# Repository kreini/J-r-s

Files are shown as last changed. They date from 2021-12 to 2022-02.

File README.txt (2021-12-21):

Járásvizsgáló eszköz

Ez az eszköz eredetileg a 29. Tudományos és Innovációs Tehetségkutató versenyre készült, melyet azóta számos alkalommal továbbfejlesztettünk, illetve számos másik versenyen is indultunk vele, mint különböző intézmények TDK-ján, illetve a 35. OTDK-n.

Ezen az adattárban az ennek a fejlesztése során létrejött programok és dokumentációk találhatók meg. A fő könyvtárak, melyek itt találhatók:

- OTDK 2021: A 35. OTDK-ra készült dokumentumok találhatók meg itt
- PosTracker: Az első 3 verzió, és a hozzá tartozó fájlokat tartalmazza
- TDK 2020 SOTE: A Semmelweis Egyetem TDK-jára készült dokumentumok
- TDK 2020: A BME-s TDK-ra készült dokumentumok helye
- TDK 2021: A BME-s TDK-ra készült dokumentumok, illetve kódok, modellek és mérések itt találhatók meg
- pályázatok: A különböző pályázatokhoz szükséges dokumentumok ebben a mappában vannak

Ez a projekt jelenleg az 5. verziónál tart, mely a TDK 2021 mappában található. Jelenleg saját NYÁK fejlesztésénél tartunk, azzal kapcsolatban lesznek további fejlesztések

Kreinicker Gábor, 2021

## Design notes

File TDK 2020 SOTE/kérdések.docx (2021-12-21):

A mi adataink milyen viszonyban vannak a már orvosilag alkalmazott eszközök adataival?

Mit jelent az, hogy „nehezen vizsgálható összefüggések”?

Mi alapján döntöttük el, hova kerüljenek a szenzorok?

Honnan jött az ötlet?

Miért van szükség két Arduinora?

Miért nem elég a Raspberry?

Mennyire megbízható egy kínai eszköz orvosi alkalmazása?

Mennyi ideig bírja akkumulátoridővel, milyen hosszú mérést lehet vele csinálni?

Miért van két érték a mintavételezésnél a táblázatnál?

Mit jelent az, hogy „elegendően pontos” a táblázatnál?

Mérünk mind a 9 DoF-ban? Miért / miért nem?

Miért van szükség az adatok utólagos ilyen szintű feldolgozására?

Hasonlítottuk-e már össze élőben a mi eszközünket más hasonló eszközökkel?

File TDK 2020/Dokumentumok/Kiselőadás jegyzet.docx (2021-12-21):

KSH:

- minden 5. felnőttnek nehézséget okoz a járás
- gyerekkorban fejlődik ki, ezért lenne jelentős a szűrése

Hasonló rendszerek

- Az orvostudomány több területein már használnak megfelelő szűrő eszközöket

Ezek jól beváltak: EKG okosóra, 24 órás vérnyomásmérők

- Probléma: A járás is nagyon fontos, mégsem szűrik megfelelően

Jelenleg használt technológiák járásszervi rendellenesség szűrésére:

- MoCap:

szobában levő kamerák veszik a páciensen elhelyezett elkülönülő pontokat, melyek pozícióját szoftveresen tudják számolni

Probléma: Sok idő, kis hely, fehérköpeny effektus

- Mienkéhez hasonló eszközök

Nagyon drágák és kis testreszabhatóság

Járáshibák:

Öt jelentős járáshiba megemlítése → ezek teljes kialakulásának megelőzése lenne a cél

- görcsös járás: feszült testtartás
- ollózva járás: a térdek befordulnak
- előre dőlt járás: ami a neve, deréktól fölfelé előre van dőlve a bácsi
- lábejtő járás: egyik lábára ráhuppan, a másikat pedig vonszolja
- vándorgó járás: felső testből oldalirányba nagy kitérések (+ gyerekeknél: lábujjhegyen járás)

A szenzorok

- MPU-9250 típusú szenzor, giroszkóp, gyorsulásmérő és magnetométer
- 7db van: 2db lábfej, 2db vádli, 2db comb és 1db derék
- Saját tervezésű és 3d nyomtatott tokozás: 3.) első verzió, 1.) harmadik verzió (most készül)

Amivel mértünk, az a második verzió (lapozás)

Az egész működése

- Az MPU szenzorok I2C buszon keresztül kommunikálnak 1-1 Ardunio Nano uvezérlővel

1 nano – 3 MPU, 1 nano – 4 MPU

- Egy szenzort akár 1000Hz-en is tudtuk olvasni, azonban több olvasásával ez lecsökkent 120-140Hz-re szenzoronként (több szenzort olvasunk + átkapcsolás)
- alvó mód → ébresztés → mintavételezés → altatás
- Az arduinok soros porton keresztül kommunikálnak a Raspberry pi 4 model B-vel, ami a beérkező adatokat a 4gb-nyi ramban tárolja, majd kimenti egy fájlba és továbbküldi vezeték nélkül (wifi) egy vele összekötött számítógépnek.

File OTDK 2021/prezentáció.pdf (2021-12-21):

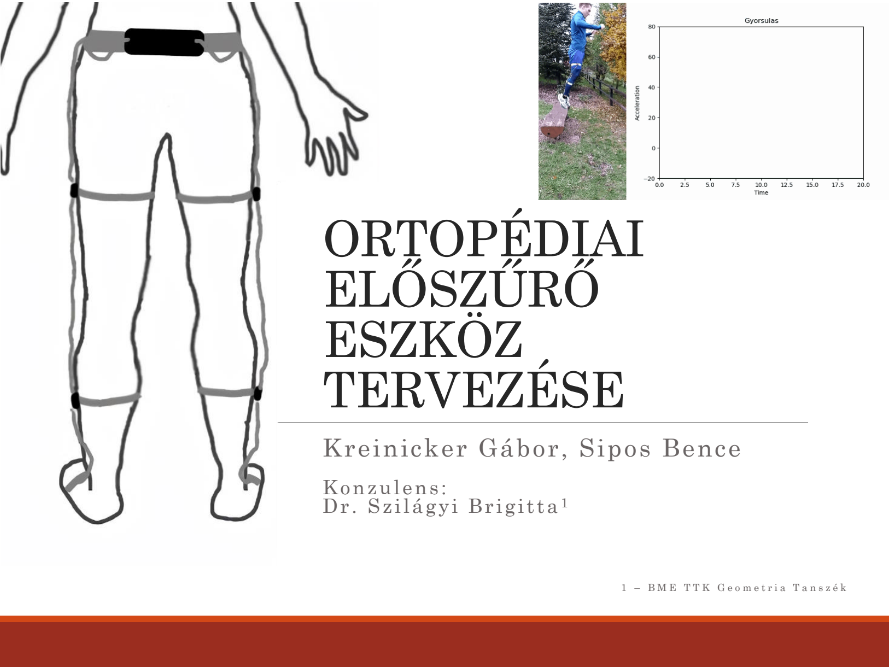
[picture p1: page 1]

# ORTOPÉDIAI ELŐSZŰRŐ ESZKÖZ TERVEZÉSE

# Kreinicker Gábor, Sipos Bence

## Konzulens: Dr. Szilágyi Brigitta ¹

1 – B M E T T K G e o m e t r i a T a n s z é k

# Járásproblémák

ORTOPÉDIAI ELŐSZŰRŐ ESZKÖZ TERVEZÉSE | 2

Képek forrása:
https://www.ksh.hu/apps/shop.kiadvany?p_kiadvany_id=1057181&p_temakor_kod=KSH&p_lang=HU

# Jelenlegi vizsgálatok

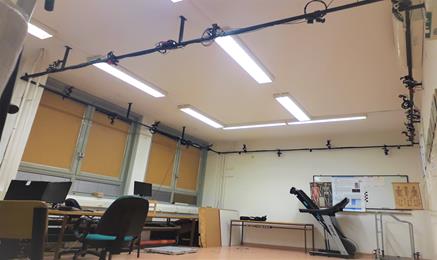
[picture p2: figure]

Képek forrása:

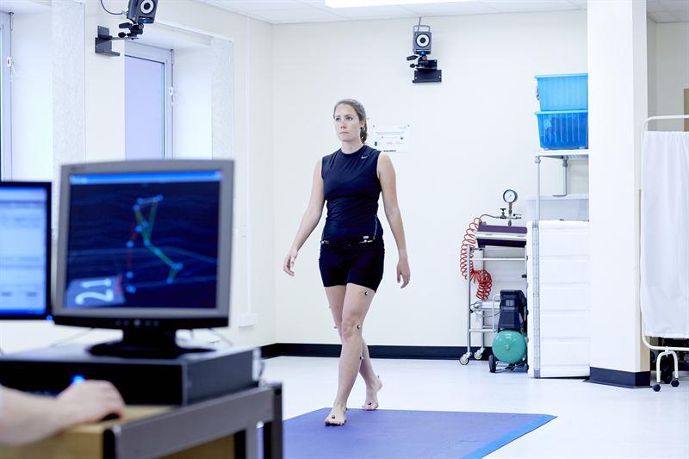
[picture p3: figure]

https://news.cision.com/vicon/r/motion-capture-set-to-become-more-mainstream-in-medical-science-predicts-vicon,c9722569 Molnár Cecília képe

# Járásvizsgálatok fontossága

# - Megfelelő időben való észlelése fontos (idősek esései) (Begg et al., 2000) - Nagyon koncentráció függő, laborban nehéz mindennapi helyzeteket szimulálni. (Bridenbaugh et al., 2011)

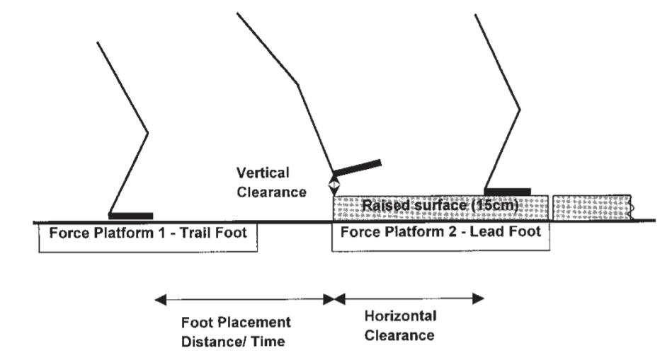
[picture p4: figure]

Kép forrása:
Begg et al., 2000

# Fehérköpeny-effektus

Képek forrása:

https://www.ncbi.nlm.nih.gov/pmc/articles/PMC6401058/

# 24 órás rendszerek

ABPM | ECG

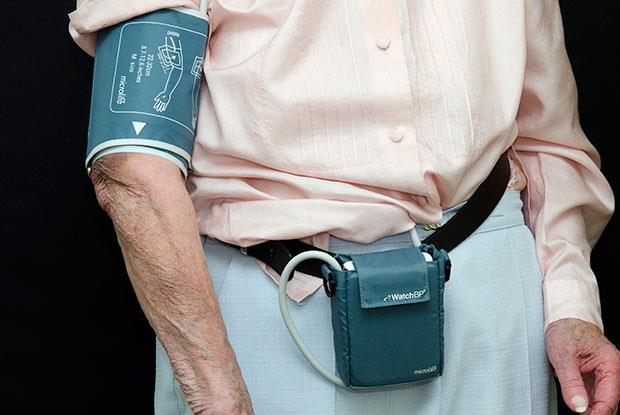
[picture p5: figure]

Képek forrása:

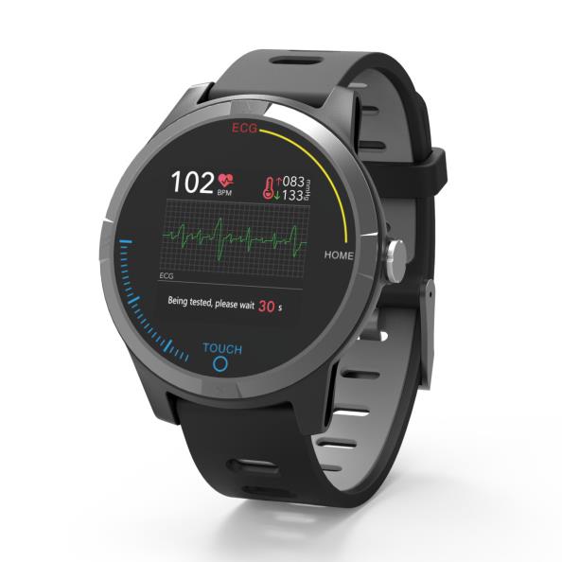
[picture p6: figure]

https://www.gponline.com/ambulatory-blood-pressure-monitoring/cardiovascular-system/article/1408835https://prixton.com/product/smartwatch-electrocardiogram-ecg-swb28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

# Nem MoCap

Képek forrása:
https://inertia-technology.com/product/motion-capture-promove-mini/https://wearnotch.com/

# Eszköz felépítése

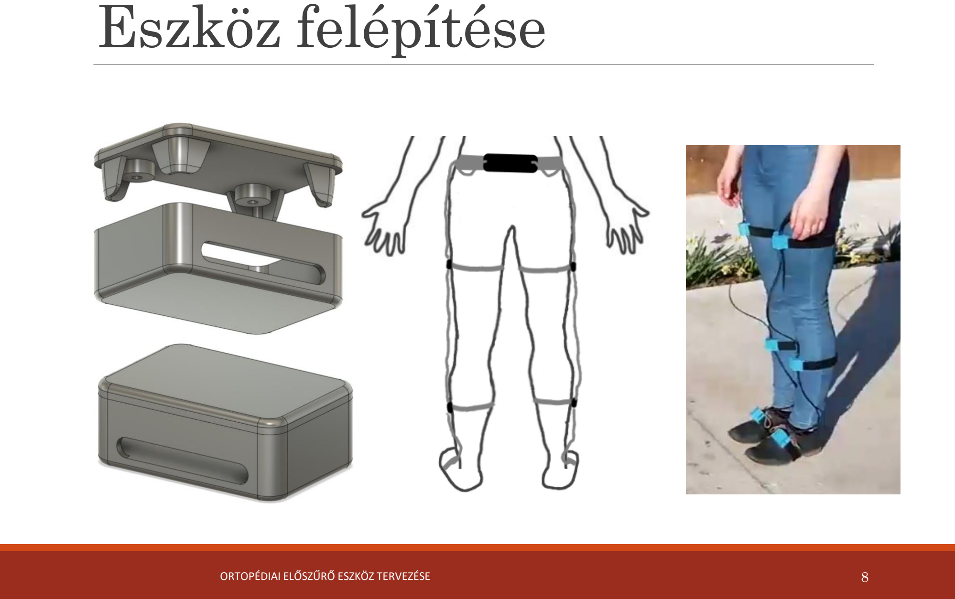
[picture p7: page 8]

# Szenzorok

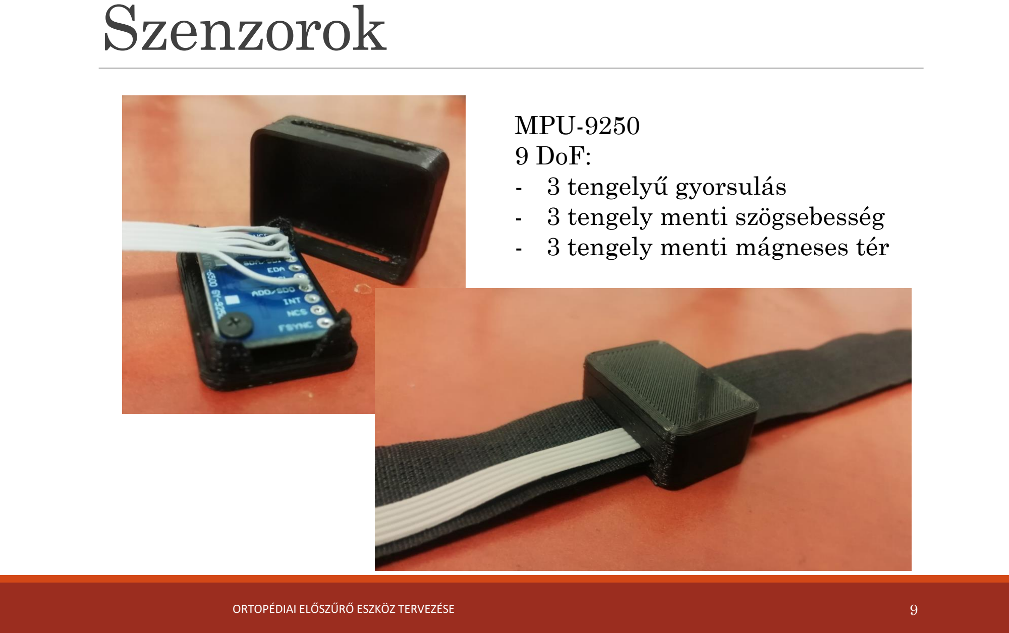
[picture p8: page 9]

# MPU-9250 9 DoF: - 3 tengelyű gyorsulás - 3 tengely menti szögsebesség - 3 tengely menti mágneses tér

# Mérőrendszer

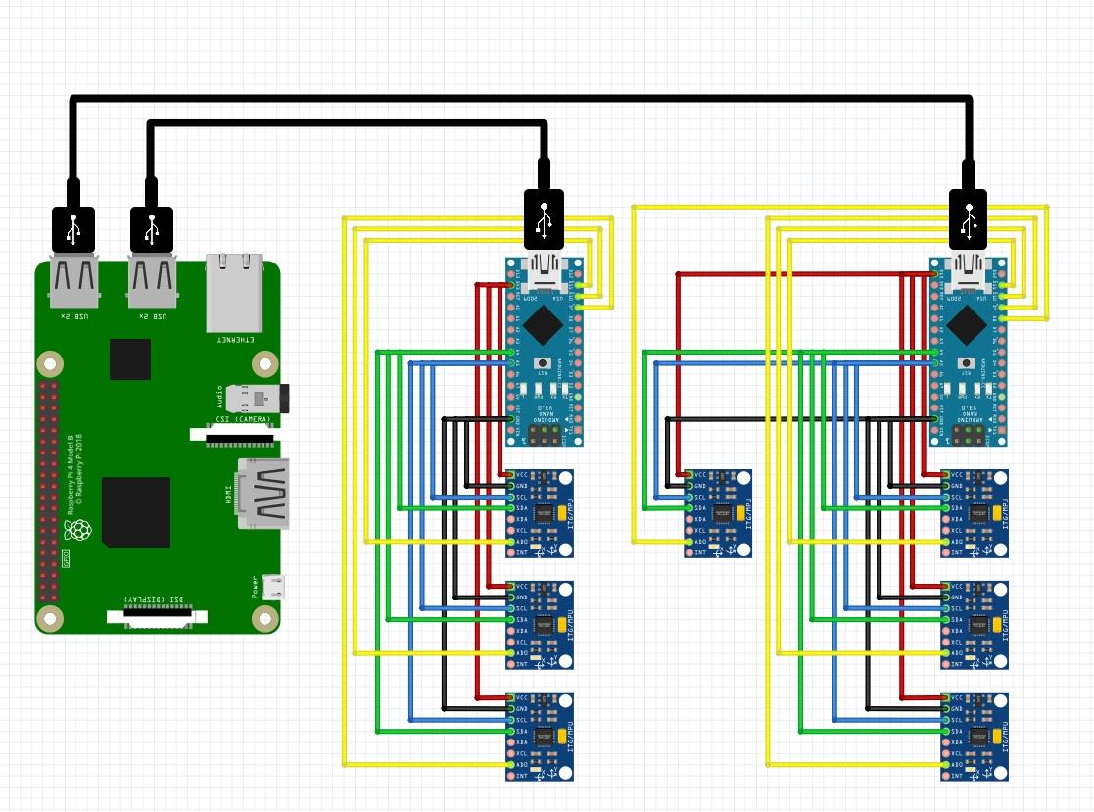
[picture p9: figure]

# Központi egység – Raspberry Pi számítógép

# Mintavételezők – Arduino Nano

# Szenzorok – MPU-9250

# Vezeték nélküli eszköz

Összehasonlítás korábbi | A mi eszközünk | Notch | ProMove-mini | MoCap/ járáslabor
megoldásokkal Ár | Alacsony | Közepes | Magas | Magas
Mintavételezés -sebesség | 120-300 | 40-500 | 500 | 120-180
Helyhez kötöttség | Nincs | Nincs | Minimális | Nagy
Kültéren alkalmazható | Igen | Igen | Igen | Általában nem
Méret és tömeg | 10 g | 10 g | 20 g | -
Pontosság | Elegendő | Elegendő | Elegendő | Nagy
Mérés maximális hossza | Hosszú | Közepes | Hosszú | Rövid
Vizsgálat előkészítés ideje | Rövid | Rövid | Rövid | Hosszú

# Mérések

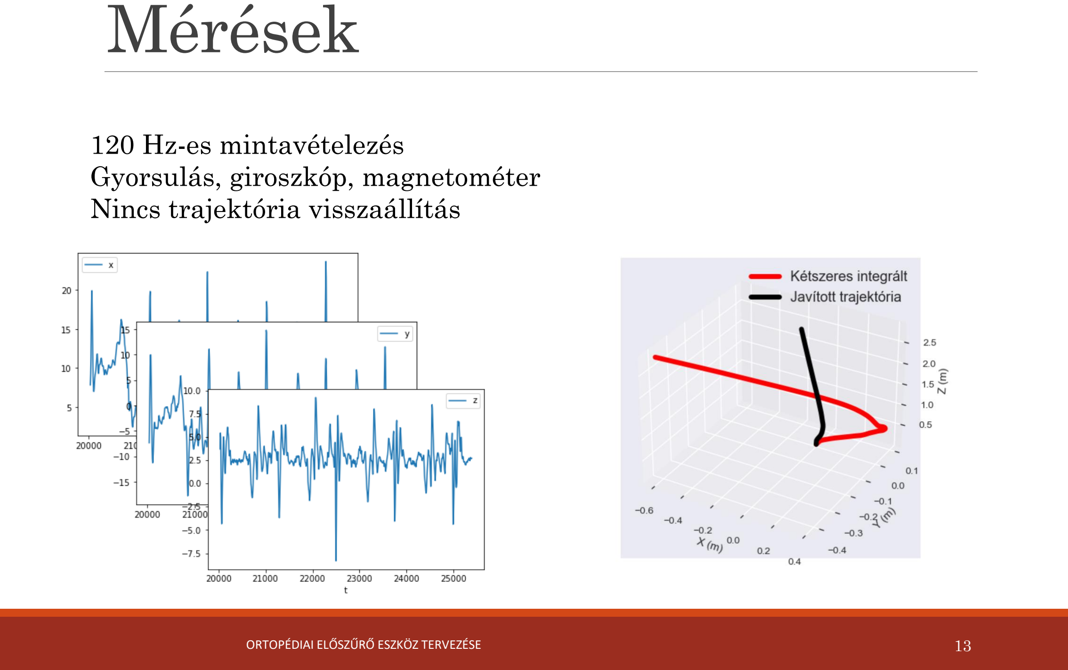
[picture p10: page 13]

# 120 Hz-es mintavételezés Gyorsulás, giroszkóp, magnetométer Nincs trajektória visszaállítás

# Adatok előkészítése

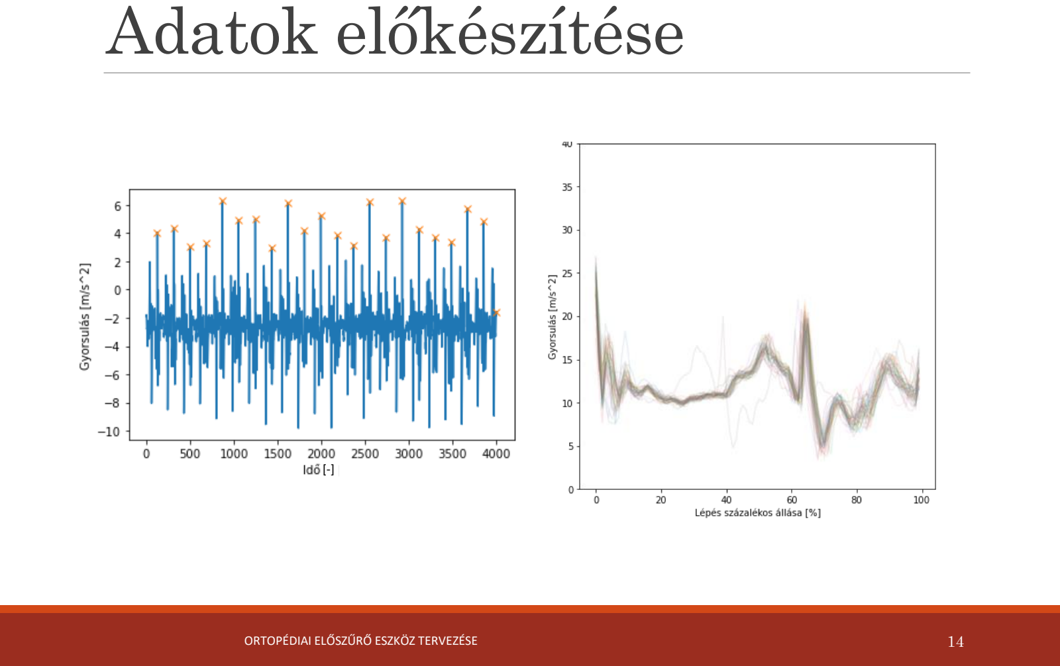
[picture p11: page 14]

[-]

# Adatok előkészítése

Kép forrása:
https://jpet.aspetjournals.org/content/321/2/423/ (https://hu.pinterest.com/pin/226446687488320272/)

# Szezonalitás dekompozíció

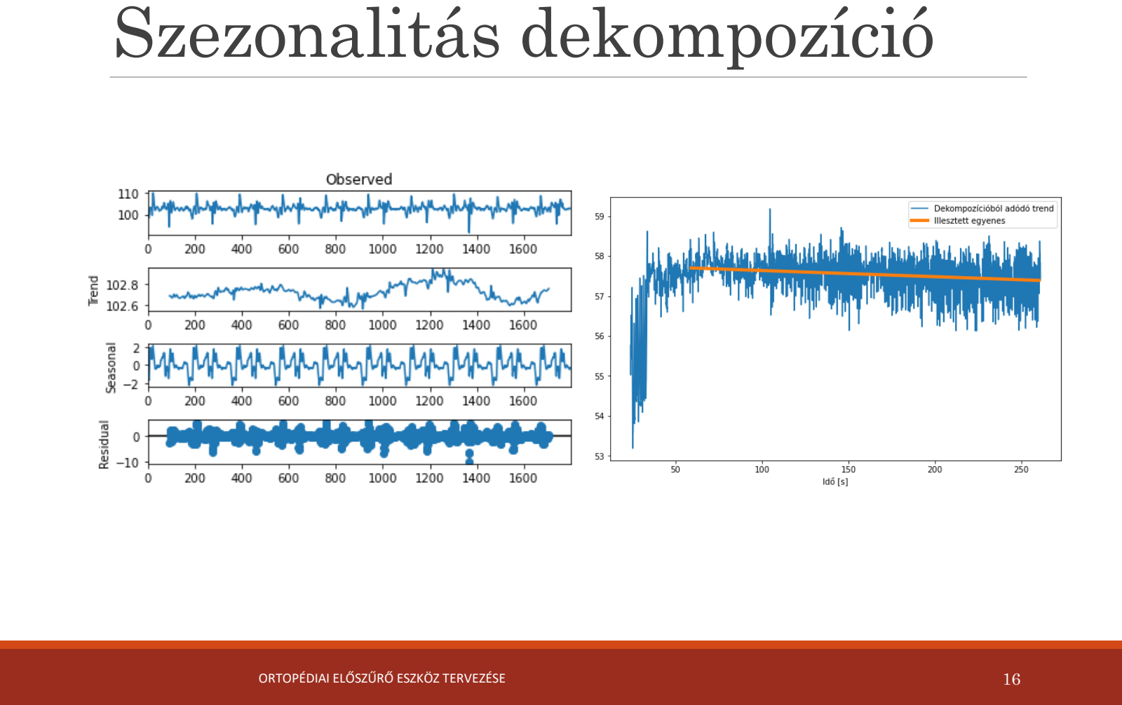
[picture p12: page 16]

# Módszerek teszteléséhez használt adatok

# -A cél, hogy ezekkel a feldolgozó módszereket teszteljük

# -Egyszerű 150 méteres séta 2 fordulással

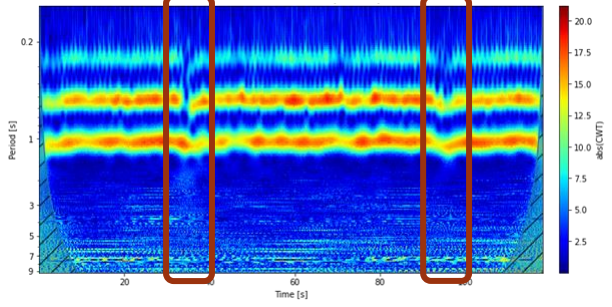
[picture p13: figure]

# Módszerek teszteléséhez használt adatok

# -Futás 15 fokos (27%-os) emelkedőn felfelé

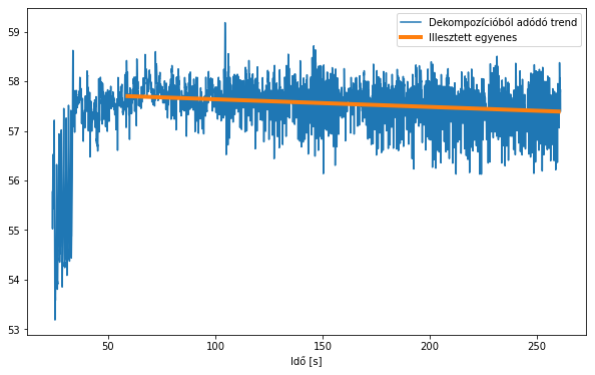
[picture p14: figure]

# Módszerek teszteléséhez használt adatok

# -Eltérő cipőtalpvastagság hatásának vizsgálata. A két láb

hossza közt ez által létrehozott 4 mm-es hosszkülönbség.

# Módszerek teszteléséhez használt adatok

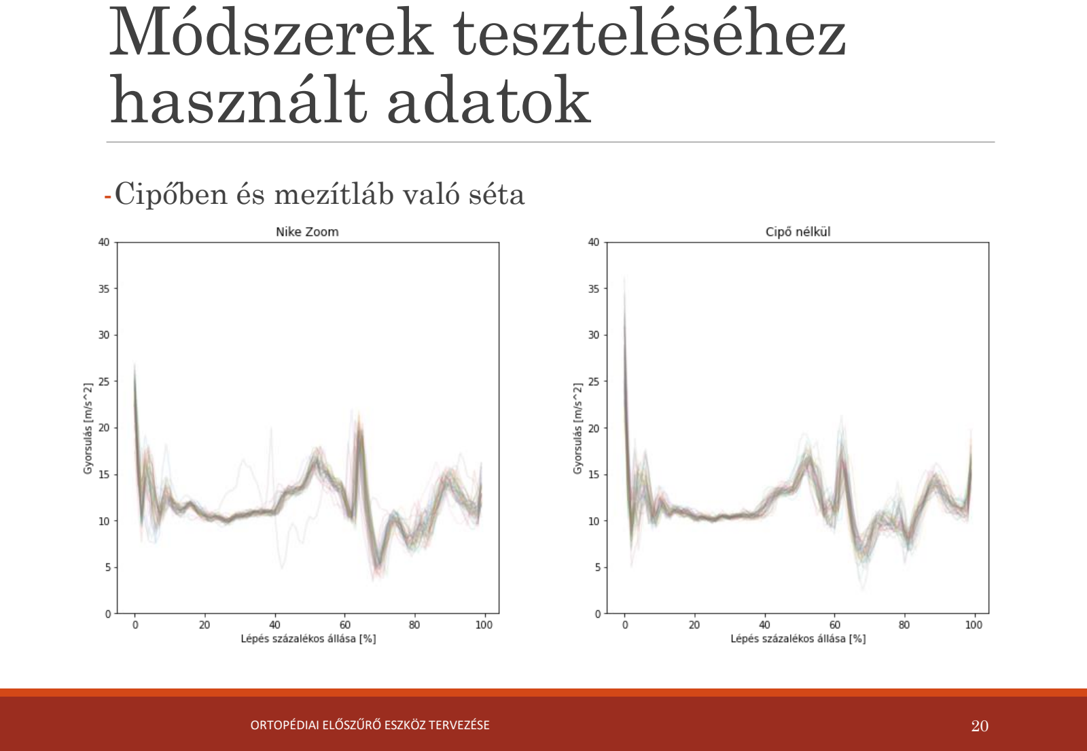
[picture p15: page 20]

# -Cipőben és mezítláb való séta

# LSTM

Mindössze 4 LSTM (Long-short term memory) cella.

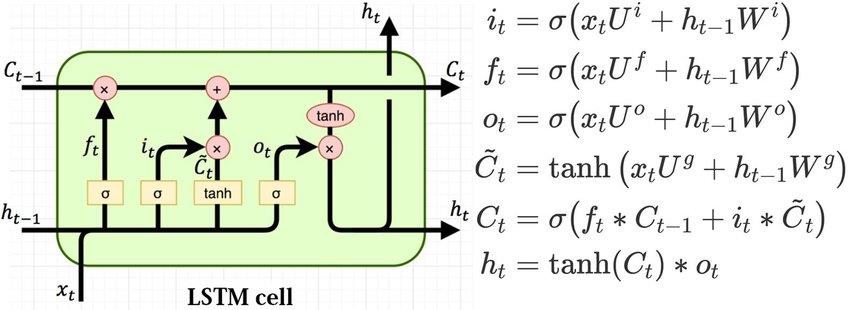
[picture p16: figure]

Kép forrása:

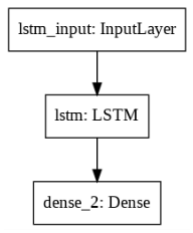
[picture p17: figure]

https://www.researchgate.net/figure/Structure-of-the-LSTM-cell-and-equations-that-describe-the-gates-of-an-LSTM-cell_fig5_329362532 (https://www.researchgate.net/figure/Structure-of-the-LSTM-cell-and-equations-that-describe-the-gates-of-an-LSTM-cell_fig5_329362532)

# 1D konvolúció

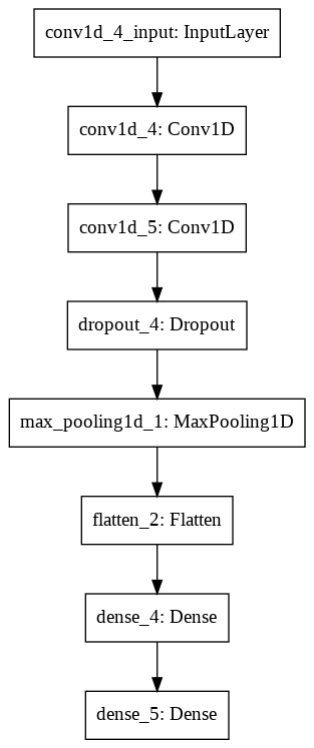
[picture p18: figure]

# -100 egység hosszú szeleteken tanítva

# -Egy-egy lépést klasszifikál

# 2D konvolúció

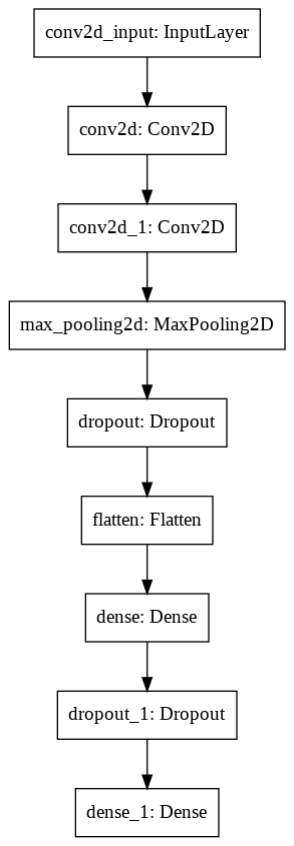
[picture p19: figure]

# -200x100-as wavelet transzformáltakból készített képek segítségével

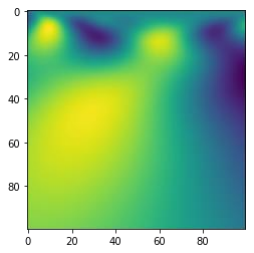
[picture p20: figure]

# Következtetések

# -Leggyorsabb: 1D konvolúció

# -Könnyű futtathatóság: LSTM

# -Legkisebb adatigény: LSTM

# -Gyorsíthatóság: 1D és 2D konvolúció

# Mérések megjelenítése

# •OpenSim és az arra épülő OpenSense segítségével

# •Adatok előkészítése Python nyelven (IMU adatok kvaterniókká alakítása)

# •Inverz kinematika számítása és plot-olás

# További feldolgozási lehetőségek

# - AI-IMU Dead-Reckoning - nyers IMU adatok feldolgozása 1,1% hibával

# - A kiterjeszett Kalman-filterbe beadott adatokat előszűri

# - SONODE - Másodrendű differenciál egyenletek feldolgozására

# - 2020 év végi újítás Norcliffe és társai munkája -> járás vizsgálatokra még senki nem használta

# - Az integrálásból adódó egyre növekvő hibát csökkenti

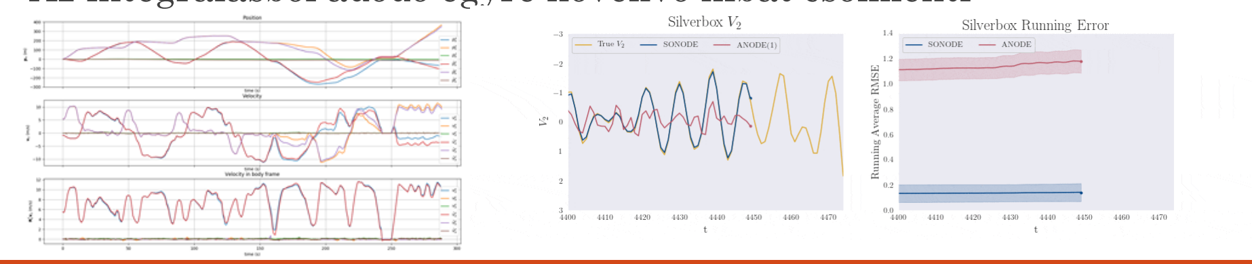
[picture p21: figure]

# Lehetséges felhasználási területek

# -Szűrésre

# -Futás, gyaloglás, labdasportok -Rehabilitáció

# -Hosszú megfigyelések például a fáradás vizsgálatára

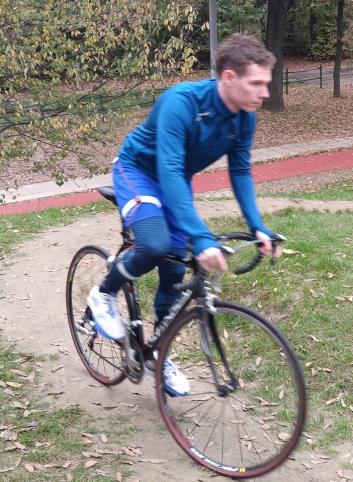
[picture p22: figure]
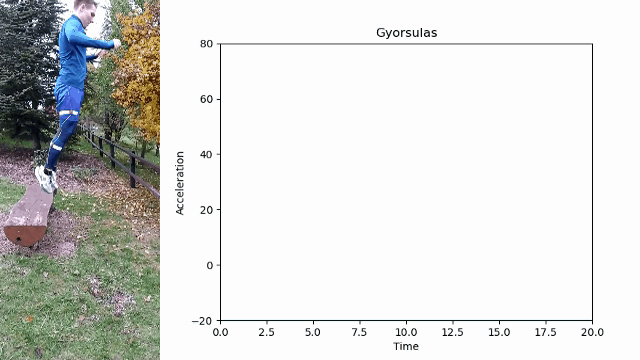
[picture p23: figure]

# Kérdések

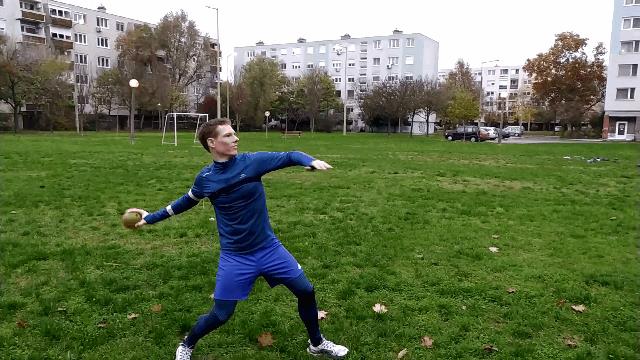
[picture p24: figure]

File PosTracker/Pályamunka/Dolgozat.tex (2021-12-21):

\documentclass[12pt,a4paper]{article}
\usepackage[a4paper]{geometry} 
\usepackage[latin2]{inputenc}
\usepackage{amsmath,amsthm,amssymb,xfrac}
\usepackage{fancyhdr}
\author{Kreinicker Gábor}
\usepackage{pgf,tikz}
\usepackage{mathrsfs}
\usepackage{graphicx}
\graphicspath{ {./images/} }
\usetikzlibrary{arrows}
\usepackage{setspace}
\renewcommand{\baselinestretch}{1}
\cfoot{\thepage. oldal}

\begin{document}
	\begin{titlepage}
		\begin{center}
			\vspace*{1cm}
		
			\textbf{PosTracker}
		
			\vspace{0.5cm}
			Járás során fellépõ rendellenességeket kimutató eszköz
		
			\vspace{1.5cm}
		
			\textbf{Kreinicker Gábor}
			
			\vfill
			
			
			
			\vfill		
		
			Szegedi Radnóti Miklós Kísérleti Gimnázium\\
			Szeged\\
			2020\\

		\end{center}
	\end{titlepage}

	Napjainkban egyre több adatot gyûjtünk, mint például az okos órák segítségével a pulzus vagy ECG, de akár gondolhatunk a telefonba épített lépésszámlálóra is, mégsem foglalkozunk járásunkkal eléggé. Sok embert érintenek a járásszervi problémák, ezek minél hamarabbi felismerése sok emberen nagyon sokat segíthet. Jelenleg a szûrõvizsgálatok sokszor idõigényesek vagy a rövidségükbõl adódóan pontatlanok. (Ilyenkor képes koncentrálni az ember és a lehetõ legszabályosabban viselkedni.) Beható vizsgálatok csak járáslaborokoban végezhetõek, melyek száma és kapacitása nem teszi lehetõvé a nagy számú szûrést.
	
	$ $
	
	A \cucc egy olyan járáshibákat kimutató eszköz, mely a járás laborok pontosságát szeretné biztosítani, annak költségessége és összetettsége nélkül. Az orvosi rendelõben, vagy akár az iskola orvos általi, a felhelyezést követõen az alany végezheti mindennapi dolgait, majd visszatérve az orvos azonnal kinyerheti az adatokat.
	
	Az eszköz a járásproblémák diagnosztikáját jelentõsen lerövidítené, ugyanis a mûszerek és a járópad hosszas elõkészületeket igényel, míg a \cucc felhelyezése csupán pár perc.  Mivel az alany nem a rendelõben lévõ járópadon végzi vizsgálatot, hanem hétköznapi környezetben, így valós, a rendelõi környezettõl és a megfelelési kényszer (az ún. \emph{fehér köpeny} effektus) hibáitól mentes adatokat kapunk. 
		
	$ $
	
	Azokat az adatokat, melyet a \cucc ki tud nyerni, jelenleg az orvosok futópadon való járásvizsgálattal és rengeteg nyomásérzékelõvel, vagy Motion Capture technológiával képesek mérni.
	
	A \emph{Nature.com} oldalán a napokban megjelent egy cikk\footnote{https://www.nature.com/articles/s41467-020-15086-2}, ahol egy az enyémhez hasonló eszközt vizsgálnak.
	
	A cikk rávilágít, hogy ezeknek a lábra erõsíthetõ gyorsulásmérõs és giroszkópos rendszereknek több hátulütõje is van. Egyrészt ezek a szenrok hajlamosak idõben elhangolódni, ami akár egy perc alatt méteres hibát is okozhat. Ezt drift-nek hívják, a kiküszöbölésére sok algoritmust fejlesztettek, de ezek használata nehéz és sokszor számítás igényes. Másrészt a technikai adottságok miatt egyszerre csak egy szenzor olvasása lehetséges. Ez két problémát idézett meg: A mintavételezések száma jelentõsen lecsökken a Motion Capture technológiával szemben. A másik, hogy az egyes szenzorok adatai idõben el lesznek tolódva. Ezekre mindre találtunk olyan megoldást, mely jelentõs mértékben kiküszöböli ezeket a mintavételezési hibákat, melyeket a feldolgozó program részletes leírásánál fejtek ki.
	
	$ $

	A \cucc megalkotását az iskolai szûrõvizsgálatokon tapasztalt pontatlan mérések ihlették. Az eszköz mûködési elvének alapját pedig az orvostudományban bevált és hazánkban is elterjedt ABPM (24 órás vérnyomásmérõ) rendszerek adták.

	Az eszköz felépítése több részre bontható: A központi eleme egy \emph{Raspberry Pi Zero W v1.1}, mely feladata a mért adatok olvasása, kimentése, és egy elõre kijelölt számítógépre küldése vezeték nélkül. Ez egy saját tervek alapján 3D nyomtatóval kinyomtatott házban van benne, melyet egy derékszíjjal az alanyra lehet erõsíteni. Ez a ház alulról nyitott, így hozzá lehet férni a \agy csatlakozóihoz, valamint innen jönnek ki a lábra erõsíthetõ szenzorok kábelei.
	
	Hét \emph{MPU9250} típusú szenzor alkotja a \cucc mintavételezõ rendszerét. Ezek képesek mérni a gyorsulást, valamint a szögsebességet x, y, és z irányban, emellett magnetométer is található bennük. Az egyik az elõbb említett házban van a  \agy mellett. A további hat szenzor lábanként a következõ módon oszlik el: 1-1 db a lábfejen, 1-1 db a vádlin és 1-1 db a combon. Ehhez szükséges a szintén saját tervek alapján 3D nyomtatott házakhoz erõsített gumiszalagra varrt tépõzárak. Minden szenzorhoz csatlakozik 5db vezeték, melybõl kettõ az áramellátás, szintén kettõ az adatátvitelhez szükséges és az ötödik határozza meg a szenzor  olvasás állapotát.
	
	Mindezek áramellátását egy \emph{Huawei} márkájú 6700 mAh-s külsõ akkumulátor szolgálja, mely a \agy háza mellett van a derékszíjra erõsítve.
	
	$ $

	A \cucc teljes használatához három program szükséges. Ezek mindegyike python programnyelven íródtak.
	
	Egyik a \agy-n levõ mintavételezõ, kimentõ és továbbküldõ program. Fejlesztés során egy olyan problémába ütköztem, hogy egyszerre csak egy szenzort tudtam olvasásra bírni. Utánaolvasást követõen megértettem, hogy I$^{2}$C buszon kommunikál a \agy a szenzorokkal, ami alapján egy szenzor két állapotban lehet: alacsony jel esetén 0x68-as címen, magas jelnél 0x69-es címen. Az állapot attól függ, hogy az AD0 láb kap-e jelet az ötödik kábelrõl a \agy-tõl. Tehát nekem csak gyorsan kell váltogatnom a szenzorok állapotát úgy, hogy mindig pontosan egy legyen a 0x68-as címen, ahonnan az olvasás történik.
	
	Ez alapján létrehozhattam egy mérési ciklust, melyek során minden szenzor egymás után egyesével aktívvá válik. Az olvasás 10 Hz-re adódott, ami azt jelenti, hogy 10 ciklus megy végbe egy másodperc alatt, tehát másodpercenként egy szenzortól tíz adatsort tudunk fogadni. Egy adatsor a hat mérendõ adatot (gyorsulás és giroszkóp 3 tengelyen), a szenzor számát, és egy idõbélyegzõt tartalmaz. Utóbbi célja, hogy a feldolgozás során idõben el tudjuk helyezni az adatokat. Ezeket folyamatosan egy \emph{kimenet.csv} nevû fájlba menti, mely a mérés megszakítását követõen küldi el a másik számítógépre.
	
	$ $
	
	A másik program a fogadó számítógépen van \emph{server} néven. Ez egy helyi szervert hoz létre, mely össze van hangolva a \agy-n levõ programmal. Ezt csak futtatni kell. Amikor adat érkezik, ez a program nekünk ki is jelzi azt. Késõbb ez a program felhõben is futtatható, így nincs szükség lokális számítási kapacitásra, illetve a feldolgozás is gyorsulhat ez által. 
		
	$ $
	
	A harmadik program a feldolgozó és megjelenítõ program. Ez további két részre bontható: egy földolgozó részre és egy diagnózis felállító részre.
	
	A program feldolgozó részének elsõ feladata az adatok szenzoronkénti, majd mért adatonkénti szétválogatása. Ezután elkészítettem egy grafikont, melybe mind a három gyorsulás és mind a három szögsebességadat benne van. Ez nem volt célra vezetõ, átláthatatlanná váltak miatta az ábrák, így szétbontottam szögsebesség-idõ és gyorsulás-idõ grafikonokra.
	
	Ez már önmagában elég lehet egy diagnózis fölállításához, azonban lehet pontosítani rajtuk. A következõ megoldásokat a derékon levõ szenzor x irányú gyorsulását vizsgáltam, de természetesen minden csatornára megoldható.
	
 	A viszonylag alacsony mintavételezés miatt az adatok igen szögletesen jelentek meg az ábrákon. Ezt próbálja orvosolni a \emph{négyzetes-spline interpoláció}, amely egy, a mért adatokat tartalmazó és a valós mozgást megközelítõ görbét hoz létre. (A \emph{szögletes-spline interpoláció} során egyre több plusz pontot építünk a mértek közé, ezzel egyre inkább próbáljuk közelíteni a valódi járás mintázatát.)
	
	A másik probléma az idõbeli elcsúszás. Elvégezve egy vizsgálatot, hogy mennyi idõ telt el két mintavételezés között, hamar feltûnt, hogy a mérés nem azonos idõközönként történik. Ennek okai a vezérlés pontatlansága és a kommunikációs hibák.A nem jól idõzített mintavételezés a spline-os interpoláció segítségével könnyen javíthatjuk, mivel a spline függvényének ismerete miatt bármely idõpillanatban kiszámolhatjuk a szenzor értékét.
	
	Ha az \emph{autokorreláció}-t alkalmazzuk egy másik mérhetõ adaton (jelen esetben az y irányú szögsebességen), akkor jól látható, hogy a periódusok kezdeti és végpontjai egy idõpillanatba kerültek és ehhez 100 mintás elcsúsztatás kell, ami az újra mintavételezés miatt 1 másodpercet jelent. Ez azt jelenti, hogy egy lépés 1 másodperc volt, ami hihetõ.
		
	A járás frekvenciáját is meg tudjuk határozni, ha létrehozunk egy periodogramot. Ezen jól látható, hogy az én általam mért alany járása $\approx$1 Hz. (Azonos az autokorrelációval kapottal)
	
	$ $
	
	A másik, diagnózist fölállító részének mûködési alapja egy konvolúciós neurális háló. Elsõ lépésben a gép számára jobban értelmezhetõ formába kellett hozni az adatokat, itt ez azt jelentette, hogy az interpolált jelet wavelet transzformáltam és az ebbõl létrejött igen hosszú képet felszeleteltem. Erre azért volt szükség, mert a nyers jelet nehéz feldolgozni és egy kis elõmunkával sokkal jobb eredményeket lehet elérni waveletek használatával. 
	
	A tanításra egy jól bevált MNIST-re használt konvolúciós neurális hálót írtam át. A gép megtanul több mintát, melyek már elõre be vannak sorolva a beteg és az egészséges tartományokba. Amint mutatunk neki egy ismeretlen járásmintát, õ képes lesz megmondani a korábbiak alapján, hogy mely tartományba eshet.
	
	Mivel nem volt meg a megfelelõ tudásom, és a határidõ is közeledett, így felkészítõ tanáromtól kaptam segítséget a gépi tanulás megalkotásához.
	
	$ $
	
	Egy mérés menete
	
	$ $ 
	 
	A jelen egészségügyi helyzet miatt lényegesen kevesebb mérésre volt lehetõségem, mint terveztem. Így most egy mérést saját magamon mutatok be.
	
	Miután fölcsatoltam magamra az eszközt és elindítottam az adatgyûjtést, nyolc percen keresztül sétáltam állandó sebességgel. A tudat, hogy rajtam van, bizonytalan járást eredményezett az elején. De a késõbbi grafikon elemzés kimutatta, hogy tartós viselés esetén egy idõ után megfeledkeztem a viselésérõl, és megfelelési kényszertõl független adatok érkeztek. Éppen ezért igyekeztem késõbbi idõintervallumot vizsgálni.
	
	Nyolc perc séta után a mérést megszakítottam, majd a két lábon különbözõ talpmagasságú cipõvel járási rendellenességet imitálva szintén nyolc percet sétáltam. 
	
	Ez után következhetett a feldolgozás. Elsõ esetben a nyers adatok szép szimmetriát, és periódikusságot mutattak, valamint észrevehetõ különbséget állapítottam meg ez és az imitált járáshibás között. Így jöhetett az autokorreláció, majd ezt követte a gépi tanulás. Véletlenszerûen kiragadva a nyolc perc sétából kettõ másodpercet a gép átlagosan $\approx$80$\%$ pontossággal fel tudta állítani a helyes diagnosztikát általa még nem látott mintán.
	
	A járáshiba egyetlen szenzor egyetlen gyorsulás csatornájából meghatározható volt $\approx$80$\%$ pontossággal. Ha a többi hat szenzort, és minden mért adatot ráállítunk a rendszerre, akkor ez még sokkal pontosabbá tehetõ. Sajnos ez bonyolultabb feladatnak bizonyult, mint terveztem, de a közeljövõben remélem sikerül, minden mért adatot felhasználni a kiértékelésnél. 
	
	$ $

	A \cucc egyszerûségének és sokoldalúságának köszönhetõen széles körben hasznosítható.
	
	Kezdve az ötletadó iskolai szûrõvizsgálatokkal. Nagyon fontos, ha egy gyermeknek járási rendellenessége van, errõl minél elõbb tudomást kell szerezni. Ezzel az eszközzel egy szûrés során nagyon egyszerûen meg tudná mondani a szûrést végzõ orvos, érdemes-e további vizsgálatra küldeni a gyermeket.
	
	A \cucc szintén jó lehet sérült emberek rehabilitációs gyakorlatainál. Nyomon lehet követni a fejlõdés irányát és mértékét jóval kevesebb szakember igénybevételével. Ez mint fiataloknál, mint idõsebbeknél hasznos lehet. Több orvostól is kaptam ígéretet, hogy amint kész van az eszköz, akkor tesztelhetem.
	
	Sportolóknál is hasznos lehet ez az eszköz. Én - a jelen állapotoktól eltekintve - rendszeresen sportolok, így tudom, milyen fontos, hogy megfelelõen mozogjunk. Például labdarúgásban kimutatható lehetne egy jól és egy rosszul elrúgott labdánál a két technika közötti különbség, és ezáltal hatékonyabban tanulhatóvá válna a lövõtechnika. Alig néhány mérést követõen bármely sportágban jelentõsen lecsökkenthetnénk a sérülések számát azzal, hogy az elejétõl fogva megfelelõ mozgás-
	technikát tanulnak a sportolók.

	$ $
	
	A \cucc sokoldalúságának köszönhetõen több továbbfejlesztési lehetõség is fönnáll.
	
	Jelenleg az érzékelõknek nagy házra van szüksége, ugyanis egy aljzatra vannak szerelve. Ennek oka a fejlesztés során történõ gyors javítási lehetõség. Azonban az aljzat elhagyásával felére csökkenthetnénk a ház magasságát, ezzel még kényelmesebbé téve a viselését.
	
	Ez a gondolat továbbvihetõ azzal, ha nem ruhára vesszük fel az eszközt, hanem egyenesen olyan ruhát készítünk, ami tartalmazza a szenzorokat. Ezeken lehetnének valamivel drágább, de praktikus és felvarrható MbientLab MetaMotion szenzorok, amelyek gombelemmel mûködnek, így vezeték nélkül is használható lenne.
	
	A \cucc -t természetesen vezeték nélkülivé lehetne tenni, azonban az szenzoronként igényelne plusz jeladót, valamint a korábban említett akkumulátor probléma miatt sem biztos, hogy célszerû lenne.(Emellett a költségeket is megnövelné.)
	
	Egy elrugaszkodott, mégis lehetséges, érdekes és sokoldalú fejlesztési lehetõség lenne, ha reverzibilissé tennénk az adatforgalmat. Elképzelhetõnek találom, hogy az olvasott jelek alapján valós idõben járást korrigáló jelet küldjünk vissza az adott testrészre. Ez történhet ingert kiváltó elektromos impulzussal, de akár egy mechanikus rendszerrel is. Ezzel lehetne gyorsítani a tanulást, vagy a rehabilitációt. Ez természetesen történhet vizuális visszacsatolással is.
	
	$ $

\end{document}

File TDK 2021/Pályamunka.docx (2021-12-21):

BME

Budapesti műszaki és gazdaságtudományi egyetem

Gépészmérnöki kar

Mechatronika, Optika és Gépészeti Informatika tanszék

Kreinicker Gábor

Tudományos Diákköri Konferencia

Mozgásszervi rendellenességek kimutatása és kategorizálása saját fejlesztésű eszközzel

Konzulensek:

Dr. Kiss Rita Mária | | Dr. Szilágyi Brigitta
tanszékvezető, egyetemi tanár | | egyetemi docens

Budapest, 2021

TARTALOMJEGYZÉK

# 1. Bevezetés

A 21. században az emberek egészségtudatosabbak, egyre nagyobb figyelmet fordítanak arra, hogy tisztában legyenek testi és mentális állapotukkal. Ennek egyik módja az okosórák használata, mellyel az aktív alvással töltött időt, a véroxigén-szaturációt vagy éppen EKG adatokat tudjuk monitorozni. Továbbá okos eszközeink GPS-ének vagy lépésszámlálójónak segítségével meghatározhatjuk a napi lefutott vagy éppen gyaloglással megtett távolságokat. A széles körben elérhető különböző applikációk különféle mozgásformák gyakorlása közben a pulzusszám figyelésével, az előre beállított testparaméterekkel kalkulálva tájékoztatnak bennünket az edzés aktivitásáról, sőt az edzést követően a regenerációs időt is meghatározzák.

Ezen alkalmazások mind-mind az egészségünket szolgálják, komolyabb mozgáselemzésre, kutatási célokra azonban nem igazán tudnak megfelelő módon adatot szolgáltatni a felhasználóknak. Én egy olyan eszköz fejlesztésén dolgozom, amely a végtagok megfelelő mozgását képes figyelni. Az általam létrehozott eszköz azonban nemcsak a mozgást szeretők örömére szolgálhat, hanem precizitása, sokoldalúsága révén kutatási, gyógyítási célokat is szolgálhat.

A helytelen mozgáskép által kialakuló szövődmények sok ember életét nehezítik meg. Ezek szűrésére jelenleg a Motion Capture (MoCap) laboratóriumokat szoktak alkalmazni. Ezt azonban csak az igazán súlyos esetek kiválogatására veszik igénybe, ilyen pontos vizsgálatokat csak indokolt esetekben végeznek, mivel a vizsgálható személyek száma alacsony és a vizsgálathoz szükséges gépek nagyon költségesek.

A MoCap egy laborhoz kötött mozgást rögzítő rendszer. A vizsgálat elején a páciensre infrareflektív gombócokat, úgynevezett markereket helyeznek fel, amelyekről több, a vizsgálat helyéül szolgáló terem/szoba felső részén helyezett kamerákból álló rendszer felvételt készít. Mivel a rögzített képek kétdimenziósak, így egy pont helyének meghatározásához legalább három kamera képe kell, amelyekből szoftveresen meg lehet határozni a pont térbeli pozícióját. A rendszer jellegéből következik, hogy így csak az adott térben tudunk mozgáselemzést végezni, ami azt jelenti, hogy néhány lépés megtételéről kapunk pontos képet. Ez azonban nem minden esetben kielégítő, gondoljunk csak a neurológiai hátterű kórképekre, ahol a páciens hosszabb monitorozása szükséges. A járáslaborokban a mozgás egy rövid szelete vizsgálható. Az is elmondható, hogy sok esetben a mérés okozta frusztráció okán nem a valós járás reprodukálódik. Hasonlóan problémás lehet különféle sportmozgások ilyenfajta laboros vizsgálata, gondoljunk csak az úszásra, labdajátékokra, de akár olyan egyszerű tevékenységre is, mint a futás. A futópadon végrehajtott mozgás különbözik még az sík terepen, például rekortánon történő mozgástól is, a természetes környezetben, terepen végzett futómozgás pedig teljesen eltér a futópadon végrehajtottól. A hosszú monitorozás folyamán válik láthatóvá a fáradás okozta változás is, ami kiemelten fontos lehet például, ha küzdősportok ütéserősségének gyengülését kutatjuk, a reakcióidő változását nézzük.


1. ábra MoCap labor mérés közben

Több éves munkám során egy olyan rendszert hoztam létre, amely tömegesen képes előszűrni a járásproblémákat, továbbá alkalmas a pácienseket megfigyelni saját, megszokott környezetükben, de alkalmazható akár vízi sportokban, labdajátékokban történő mozgáselemzésre is. Mindezek ellenére a járáslaborok kiváltása nem cél, mivel a pontos kvantitatív vizsgálatok elvégzése csak azokban lehetséges.

Sipos Bencével közösen írt, korábbi TDK munkámban bemutattuk az eszköz első verzióját [1]. Egy hosszú megfigyelést lehetővé tevő, új eszközhöz ötletet adott a 24 órás vérnyomásmérés (ABPM) és a 24 órás EKG vizsgálat (Holter). Célunk volt, hogy könnyen kezelhető eszközt fejlesszünk, mert akkor nagylétszámú szűrővizsgálatok is végrehajthatók. A rehabilitáció folyamatában pedig az egyszerű alkalmazhatóság lehetőséget ad arra, hogy a beteg fejlődése jól követhető legyen. Eszközünk lehetőséget biztosít arra is, hogy egy sportoló esetén egy adott mozdulat javításában támaszkodjunk rá ezzel segítve a helyes technika kialakulását.

# 2. Szakirodalmi áttekintés

A szakirodalmi áttekintés három részre bontható: a vizsgálandó mozgásszervi rendellenességek orvosi hátterei, a járással kapcsolatos statisztikák és a piacon jelenleg megtalálható, hasonló technológiát alkalmazó eszközök bemutatására.

## 2.1. Orvostudományi háttérismeret

Ahhoz, hogy egy orvosi célokra alkalmazható eszközt létrehozzunk, valamennyire tisztában kell lenni a probléma biológiai hátterével, valamint azzal, hogy milyen eredményeket szeretnénk elérni. Eleinte a különböző járáshibák kimutatása volt a célunk, mivel megfelelő esetekben egymástól jól elkülöníthetők a járás karakterisztikák. Járáshibáról, vagy mozgásszervi elváltozásról akkor beszélhetünk, ha a megfelelő erőbefektetés, megfelelő koordináció vagy megfelelő érzékelés valamelyike nem teljesül. Effajta hibák kialakulásának számos oka lehet, mint genetikai tényezők, betegségek, sérülések vagy elváltozások az alsó végtagban.

A szakirodalom a következő típusú mozgásszervi rendellenességeket különíti el: van az úgynevezett bénult járás (spastic gait), amikor az alany talpa sosem emelkedik el teljesen a földtől. Emellett van az ollózás (scissors gait), ekkor a lábfejek egymás felé vannak fordulva. A lábejtés (steppage gait) során az alany járás közben lábujjhegyét végighúzza a talajon. Vándorgó járás (vaddling gait) esetén az alany oldalirányba nagy kilengéseket tesz felső testből. Az ötödik típus az előre hajló járás (propulsive gait), ekkor az alany felső teste a csípő elé helyeződik.

A képen szöveg, vázlat látható Automatikusan generált leírás

2. ábra Járásproblémák [2]

A járáshibák kialakulásának eredetét három csoportra bonthatjuk: Ortopédiai eredetűre, amely esetén az alsó végtag ízületei károsodtak, kardiovaszkuláris eredetűre, amikor a mozgásszervek vérellátása nem megfelelő és neurológiai eredetűre, amely esetén az alany agyának károsodása okoz mozgáskoordinációs problémákat. Jelenleg ezek egymástól való elkülönítése nehézkes, így előfordul, hogy nem megfelelő ellátásban részesülnek a páciensek.

Mivel az általam fejlesztett eszköz alkalmas hosszú idejű mérések kivitelezésére, így a neurológiai és a kardiovaszkuláris eseteket is képes lehet kimutatni. Ennek oka, hogy ezen eredetű járáshibák rövidtávon nem jelentkeznek, azonban hosszabb vagy terheléses teszt esetén lehetséges a megfigyelésük.

## 2.2. Statisztika

A National Center for Biotechnology Information (NCBI) egy 1999-es kutatása során [3] kimutatták, hogy a 70 éves kor felettiek több mint harmada szenved valamilyen mozgásszervi rendellenességben, ahol a neurológiai és nem neurológiai eredetű esetek többnyire egyenlő megoszlást mutattak.


De nem is kell messzire menni, ugyanis a Központi Statisztikai Hivatal (KSH) 2019-es egészségügyi felmérése alapján [4] a magyar felnőttek 25%-a nem jár megfelelően. Ez azért veszélyes, mert a későbbiekben ez vezet majd további szövődmények kialakulásához. Megfelelő, széles körű szűréssel ezek elkerülhetőek lehetnének.

3. ábra Járáshibák Magyarországon

Egy külföldi kutatócsoport a combnyaktörés kialakulásának fő okát, az egyensúlyvesztést vizsgálta [5]. A vizsgált alanyok feladata egy, a labor közepén elhelyezett, 15 cm-rel megemelt platformra való felállás volt. Megdöbbenésükre minden alany gond nélkül, többször is végrehajtotta a feladatot, azonban otthon mégis elestek hasonló terepviszonyok mellett. Megállapították, hogy ennek az az oka, hogy míg a laboratóriumban csupán a platformra való felállás az egyetlen feladatuk a pácienseknek, addig otthoni, megszokott környezetükben megoszlik a figyelmük, és ez okozza az egyensúlyvesztést. Az általam fejlesztett eszköz éppen az ilyen típusú esetek kimutatására lenne igazán alkalmazható.


4. ábra Fellépés kísérlet

## 2.3. Hasonló eszközök a piacon


Azt a technológiát, amely az eszközömben is jelen van, számos helyen alkalmazzák. Megtalálhatók okostelefonokban, melynek köszönhetően működnek a telefon döntését érzékelő játékok, továbbá kormány nélküli elektromos járművekben, digitális iránytűkben és egyéb okos eszközökben. Megtalálhatók a piacon az enyémhez hasonló, testre rögzíthető szenzoros eszközök, mint az Xsens DOT [6] vagy a Notch [7].

5. ábra Xsens DOT és Notch

Ez a két eszköz hasonló árban van, azonban felhasználási területük igen eltér. A Notch felhasználása elsősorban a fitnesz és yoga mozdulatok valós idejű monitorozására terjed ki, míg a DOT egyéb sportok mozgásának rögzítését veszi célba. Ez utóbbit használták például a FIFA 22 nevű labdarugó játékszoftver esetén is, ahol a cél a futballisták mozgásának legprecízebb átültetése volt a játékba.

Ami azonban nagy különbség a megvásárolható eszközök és a magam fejlesztette eszköz között, hogy ezek nem orvosi célokra készültek. Emiatt számos hátrányuk van, mint az üzemidő vagy az adatok felbontása. Ezen eszközök technikai adataira a későbbiekben kitérek, ahol összehasonlítom őket az én eszközömmel a legfontosabb orvostani paraméterek alapján.

# 3. A hardver fejlesztésének lépései

Amikor elkezdtünk foglalkozni a problémával, akkor még egy egészen más koncepciónk volt az eszköz kialakításáról és működéséről. Nem tudtuk, hogy milyen felbontás elegendő, hogy milyen értékekkel kell számoljunk, illetve, hogy van-e egyáltalán értelme orvosi célokra használni egy ilyen adatokat szolgáló eszközt. Éppen ezért számos prototípus elkészült az elmúlt időben, amelyekkel igyekeztünk minél nagyobb tapasztalatot szerezni az előbb említett bizonytalan témákban. Ezeket a következőkben rövid jellemzéssel és összehasonlítással bemutatom.

## 3.1. Vezetékes rendszerek


Első verziójú prototípusunk MPU9250 típusú 9 szabadsági fokú, úgynevezett IMU (Internal Measurement Unit) szenzorokból állt. Ez annyit jelent, hogy 3-3 lineárisan független tengelyek mentén mintavételezünk gyorsulás, giroszkóp és magnetométer adatokat.

6. ábra Az első prototípus végleges megjelenése

Ez a prototípus 10 Hz-es felbontásra volt alkalmas, ami azt jelenti, hogy minden szenzor másodpercenként tízszer küld adatot egy központi mikroszámítógépnek, ami ebben az esetben egy Raspberry Pi Zero W mikroszámítógép volt. Innen küldtük tovább vezeték nélkül a mérés végén az adatokat egy előre kijelölt számítógépnek.

Számos probléma volt ezzel az eszközzel, mint például az alacsony felbontás, mely jelentősen megnehezítette az adatok feldolgozását. Továbbá elkerülhetetlen volt egy olyan technológia alkalmazása, ami bár lehetővé tette egyidőben 7 szenzor alkalmazását, de az adatok elcsúsztak egymástól, amit ilyen felbontás mellett nehezen lehetett korrigálni.

A második prototípusunk is vezetékes volt, de már jóval kisebb, kényelmesebben viselhető és akár 120 Hz-es felbontást is el tudtunk vele érni. Ennek egyik fő oka, hogy lecseréltük a mikroszámítógépet két Arduino Nano mikrokontrollerre és egy, a korábbinál jóval nagyobb teljesítményű Raspberry Pi 4 model B mikroszámítógépre. Mivel nem belső tárhelyre, hanem a RAM-ba mentettük az adatokat, így jóval gyorsabban tudtunk mintavételezni.


7. ábra A második prototípus felépítése

## 3.2. Vezeték nélküli rendszerek

Bár jelentősen javultak az eszközünk legfontosabb paraméterei, de szükségét láttuk áttérni teljesen vezeték nélküli eszköz fejlesztésére, ugyanis azt tapasztaltuk, hogy az alanyok sokkal nehezebben feledkeznek meg róla, hogy éppen mérésben vesznek részt, mint egy vezeték nélküli esetben, továbbá a vezetékek akadályozhatják a résztvevő személyt bizonyos mozdulatok végrehajtásában. Így alakult, hogy vásároltunk több kínai Lilygo TTGO nevű okosórát [8], melyek rendelkeznek IMU szenzorokkal. Azonban, hogy ezeket használni tudjuk, egy teljesen új programkódot kellett létrehoznunk. Bár a fejlesztése igen nehézkesnek bizonyult a kevés elérhető irodalom és bonyolult hardverstruktúra miatt, azonban mindezek ellenére akár 300 Hz-en is tudtunk mintavételezni. Sajnos az akkumulátor kapacitásával sem voltunk megelégedve, alig 30 perces méréseket tudtunk végezni az eszközzel.


8. ábra Az átalakított okosóra

## 3.3. A mérések során alkalmazott eszköz

Irodalomkutatásaim során találtam rá a Sparkfun cégre, akik egy Openlog Artemis nevű eszközt fejlesztenek [9]. Ez rendelkezik a számunkra szükséges IMU szenzorral, mely szintén 9 szabadsági fokú. Továbbá alkalmas vezeték nélküli kommunikációra, mellyel szinkronizálni tudjuk az érzékelőket, valamint elhelyeztek rajta egy memóriakártya-olvasót is. Ez az eszköz csak mintavételezést végez, a nyers adat feldolgozása teljes mértékben utólag megy végbe.


9. ábra A Sparkfun Openlog Artemis

Mivel ezt az eszközt elsősorban elektromos gördeszkák motorszabályozásához szokták használni, így szükséges volt némi átalakítást végezni rajta. Egyrészt hardveresen is módosítanunk kellett az áramkört: egyik ilyen volt egy lítium-ion akkumulátor beszerelése, hogy az eszköz vezeték nélkül is akár 8 órán keresztül üzemképes legyen. Továbbá szoftveresen ki kellett bővíteni a mintavételezési sebességet, illetve a méréshatárokat, ugyanis futás, ugrás és egyéb gyakorlatok közben ennek szükségét tapasztaltuk.


Ehhez az elkészült elektronikához készítettem egy tokozást, mely védi az esetleges ütésektől és mellyel megkapja a jellegzetes, virágszirom alakját. Dimenzióit tekintve átlagos okosóra méretű, amelytől valamivel vastagabb, így a méretei nem korlátozzák a pácienst a mozgásban. Ezekből jelenleg kettő készült el, de célunk egy hatos szett összeállítása, mely az idő rövidsége miatt ezidáig sajnos nem valósult meg.

10. ábra A jelenleg alkalmazott eszköz végleges formájában

Korábban kiemeltem az eszközömhöz leginkább hasonlító eszközök közül kettőt, melyek az Xsens DOT és a Notch. Ezeket a számunkra legfontosabb paraméterek alapján hasonlítottuk össze, beleértve a MoCap rendszert, mely utóbbi nem feltétlen releváns, de egy összkép felállításához segítséget nyújthat. Ezek a paraméterek a technikai, felhasználhatóságbeli és árbeli tulajdonságok.

A képen asztal látható Automatikusan generált leírás

11. ábra Az eszközök összehasonlítása

## 3.4. Jövőbeli fejlesztések


Bár már megkezdtük a hitelesítést a jelenlegi eszközzel, azonban hosszabb távú céljaim közé tartozik egy teljesen saját fejlesztésű nyomtatott áramkör elkészítése. A tervezés már előrehaladott állapotban van, elkészültnek tekinthető. Azonban több, mostanra bevált alkatrész gyártásával már nem foglalkoznak, így jelenleg alternatív megoldás felé kutatok.

12. ábra A jövőben elkészülő áramkör renderelt megjelenése

Ennek hatalmas előnye az összes korábbi prototípussal szemben, hogy fejlesztési szempontokat figyelembe véve könnyedén bővíthető. Továbbá akár 500 Hz-es mintavételezési sebességet is el tudunk érni, ugyanis a hardveres korlátokat, melyek számunkra nem szükséges funkciók okoznak, egyszerűen kihagyjuk. A Bluetooth modul és a kártyaolvasó gördülékeny mérést fog eredményezni.

# 4. Mérések és adatfeldolgozás

Ebben a fejezetben az eszközünkkel végzett mérések menetét és céljait, valamint az ekkor gyűjtött adatok feldolgozását fogom bővebben kifejteni.

## 4.1. A hitelesítés

Az elmúlt időben két fő célunk volt: az eszközünk minél jobbá tétele és a hitelesítési és validálási folyamat megkezdése. Ahogy korábban bővebben kifejtettem, számos prototípuson túl vagyunk már, és bár még nem a tökéletes eszköz van a kezemben, de hatalmasat fejlődött az elmúlt időben.

A hitelesítési és validálási folyamat nehezebben haladt a jelen vírushelyzet miatt. Csupán mostanára sikerült megkezdenem a hitelesítő méréseket, melyhez a BME MOGI Tanszék MoCap laborja nyújtott lehetőséget, ahol az ott felszerelt Motion Capture rendszerrel hasonlítottam össze a saját eszközömet. A hitelesítés során igyekeztünk minél sokszínűbb mozgássorozatokat vizsgálni mind a felső, mind az alsó végtagokon.


A két különböző eszköz összehasonlíthatóságához egy-egy három markeres, testre rögzíthető szíjra erősítettem fel a saját eszközeim közül egyet-egyet úgy, hogy a három marker alkotta háromszög súlypontjába essen a szenzor, ezzel megkönnyítve a későbbi adatfeldolgozást.

13. ábra A szenzor-marker kombináció

A mérendő feladatokat két részre bontottam: egyik csoportba a kézmozgást vizsgáltuk, mely esetben az alkarra és a felkarra került egy-egy érzékelő, vagy a lábon helyeztük el az érzékelőket, egyet a combra és egyet a lábszárra. Másik csoportban pedig rövidebb, csak az én eszközöm által mintavételezett méréseket végeztem, ahol a szenzor határait feszegettem, milyen érdekes jelenségeknek a kimutatására alkalmas.

### 4.1.1. A hitelesítés során végzett feladatok

A hitelesítés során vizsgált alanyok feladatai a következők voltak:

1. Asztalsöprés: Az alany végig simít egy sík asztalt a karjával. Oda-vissza tízszer ismétli meg a feladatot. Mivel ebben az esetben vízszintes irányban kényszerek hatnak a kézfejre, így az ezirányú gyorsulásnak a nehézségi gyorsulással kell egyenlőnek lennie.
2. Bokszolás: Az alany vállmagasságban hirtelen mozdulattal előre nyújtja a kezét, mindezt tízszer ismételve. Ez a mozdulat gyors, így hirtelen nagy gyorsulások figyelhetők meg.
3. Nyomás: Az alany a karjait függőleges irányban kinyújtja, majd visszaengedi a mellkasára. Ezt tízszer-tízszer kell megismételni gyors, illetve lassú mozdulatokkal. Ezzel függőleges irányban minimalizáljuk a gyorsulásértékeket.
4. Karemelés: Az alany a karjait maga mellől a feje fölé emeli, majd engedi vissza, mindezt tízszer ismételve. Mivel a kézfej közel körpályán halad, így ez könnyen ellenőrizhető.
5. Karnyújtás: Az alany nyújtott karral maga elől mellkas magasságig emeli fel kezét és engedi vissza tíz ismétléssel. A karemeléshez hasonlóan ez is könnyen visszaszámolható.
6. Ugrás: Az alany egymás után tíz alkalommal ugrik többnyire állandó magasságra. Itt maximális gyorsulásokat tudunk elsősorban megfigyelni, ezáltal méréshatárokat vizsgálni.
7. Térdhajlítás: Az alany felül egy padra a combját alátámasztva. Ezt követően 10-10 alkalommal lógó helyzetből kinyújtja a lábát lassan, illetve gyorsan (rúgás). Mivel a comb alá van támasztva, ezért annak bizonyos gyorsuláskomponensei nullák lesznek, míg a lábszáron elhelyezett szenzorokra nagy gyorsulások hatnak.
8. Séta: Az alany a teremben oda-vissza gyalogol 5 percen keresztül. Itt az adatok időbeli elcsúszását, illetve változását tudjuk nyomon követni.
9. Futás: Az alany futópadon szoktatás után 5 percen keresztül 8 m/s-os sebességgel fut. Ekkor az alany fáradásából adódó gyorsulás-változásokat, illetve a sétához hasonlóan az adatok elcsúszását tudjuk vizsgálni.

### 4.1.2. Adatfeldolgozás

Ezek alapján állnak rendelkezésemre a saját eszközömből származó, elsősorban gyorsulás adatok és a MoCap rendszerből származó pozícióadatok. Ezek összehasonlítása egyáltalán nem triviális, ugyanis vagy a gyorsulás értékek alkotta görbét kell kétszer integrálnom, vagy a pozíció adatokat kell kétszer deriválnom. Sajnos, mindkét esetben akadnak problémák: az elsőben eltolódnak az adatok, azaz nem hiteles a mérés, mivel korrigálni sem tudjuk. Emiatt a későbbiekben sem próbálkoztam trajektória visszaállítással. A deriválásnak pedig az a nagy hátránya, hogy a jel zaját felerősíti, ezzel megnehezítve az összehasonlítást.

Az utóbbi lehetőséget választottam, mert annak a hátrányait könnyebben tudjuk kezelni, mint az integrálás okozta hibákat. Először egyszerű differenciálszámítással határoztam meg a markerek gyorsulásait, amely nem bizonyult megfelelő eljárásnak. A zaj a vártnál is jelentősebb volt, megjelenítést követően nehezen kivehetők voltak a tényleges gyorsulásértékek. Ami azonban hatalmas előrelépés volt, hogy minden zaj ellenére hasonlított egymásra a két teljesen eltérő technológiát alkalmazó eszközből, berendezésből származó jel.


14. ábra MoCap és saját adatok összehasonlítása

## 4.2. További mérések végzése

Annak érdekében, hogy megismerjem az eszközeim határait, végeztem több, a hitelesítéstől független mérést, hogy demonstráljam a sokoldalúságát. Ahogy korábban említettük, a jelenleg is teszt alatt álló eszközünk gyorsulás, giroszkóp és magnetométer adatokkal szolgál (x-, y- és z-tengelyek irányában), ezeket 100 Hz-en mintavételezve. Bár ezek mindegyikének mérésére van lehetőségünk, de a későbbiekben úgy véltem, hogy elegendő a gyorsulás értékeket vizsgálni.


A nyers adatok önmagukban nem mondanak sokat, így szükség van azok könnyen érthető megjelenítésére, vizualizációjára. Ennek legegyszerűbb módja a nyers adatok ábrázolása az idő függvényében. Mivel a különböző mozgások vizsgálatára eltérő időintervallum szükséges, ezért ezt dinamikus módon tettem meg.

15. ábra Nyers gyorsulásadatok (x, y, z) bázisban


Mivel az eszközöket pántokkal erősítettük a végtagokra, így emiatt és ezen testrészek rugalmasságából adódóan nagy gyorsulásokat követően a mozgásszervek mozgásához hozzáadódik egy tranziens viselkedés. Diszkrét konvolúciót alkalmazva ezt a jelenséget jelentősen le tudtam redukálni, azonban nem minden esetben használható. Hirtelen irányváltás esetén ugyanis a valódi gyorsulásértékeket is korrigálja, ezáltal torzítja a járásképet. Ezekben az esetekben az eszköz olyan rögzítésére van szükség, ami annak elmozdulását meggátolja.

16. ábra Korrigált gyorsulásadatok

Use of Wavelet and Fast Fourier Transforms in Pharmacodynamics | Journal of Pharmacology and Experimental Therapeutics

Mint az könnyedén megállapítható, a járás megfelelő esetben periodikus. Periodicitás esetén pedig a jelet érdemes frekvenciatartományba átvinni. Két eljárást próbáltam ki ennek elvégzésére: a Fourier-transzformációt [10], és a wavelet analízist [11].

17. ábra Fourier-transzformáció és wavelet analízis

A Fourier-transzformáció nagy előnye, hogy a mozgás bizonyos paramétereit frekvenciatartományban sokkal egyszerűbben és szemléletesebben lehet megállapítani és megjeleníteni, mint időtartományban. Azonban ekkor elveszítjük az időtől való függést, amely terheléses vizsgálatok esetén fontos szempont. Ennek áthidalására használják a Gyors Fourier-transzformációt (Fast Fourier Transform – FFT) egyik kapcsolódó eljárását, a Short-time Fast Fourier Transformationt (STFT), mely esetben az időtartománybeli jelet először rövidebb szakaszokra bontjuk, majd ezután végezzük el az FFT-t.

A wavelet analízis elméleti háttere könnyedén összehasonlítható az STFT-vel, ugyanis míg az STFT állandó időintervallumokra bontja a jelet, addig a wavelet-transzformáció esetén dinamikus módon, a frekvenciától függő szakaszokra. Ezt a módszert a rádiócsillagászatban hosszú periódusú változó csillagok mérésére sikeresen alkalmazzák több mint húsz éve. Járásvizsgálat esetén ez a módszer azért hasznosítható, mert így a mozgás sebességének változásai szépen megjeleníthetők.


Így történt ez az alábbi ábrán láthatóan is, mely mérés során egy 150 méteres mozgást rögzítettünk, amely alatt a mérésben résztvevő személy kétszer megfordult, ami jól látszik a folytonos wavelet tanszformálton. A fordulás a 37 és a 94 másodperc környékén volt, ahol a járás üteme megváltozott, egy kissé lelassult korábbi sebességhez képest.

18. ábra A 150m-es séta wavelet-transzformáltja

### 4.2.1. Lépésanalízis


A következőkben a korrigált gyorsulásadatok közül az y-irányú adatok vizsgálatát fogom mélyebben elemezni. Ennek egyik módjaként a programkódban kirajzoltattam a lokális maximum helyeket. Ezek mentén feldaraboltam a jelet, melyek egyenként egy-egy lépés karakterisztikáját adják meg. Ezeket egymásra illesztve láthatjuk, hogy az adatunk konzisztens marad, nem térnek el a lépések egymástól számottevően.

19. ábra Egymásra illesztett lépések


Ennek a technikának a használatával korábban megvizsgáltuk egy páciens futásának gyorsuláskarakterisztikáit, amely esetben egyik alkalommal cipőben, másik alkalommal mezítláb végezte a feladatot. Jól látható, hogy első esetben közelítve 30%-kal kisebb gyorsulások hatottak lábletételkor (vizsgált lépés kezdőpillanata) az alanyra, mint cipő nélkül.

20. ábra Lépésvizsgálat cipővel és cipő nélkül

### 4.2.2. Bicepsz vizsgálat


Pusztán véletlen eszembe jutott, hogy a saját és edzőtársam felkarjára helyezzek 1-1 darabot a szenzorjaimból. Egy bicepsz gyakorlat kézi súlyzóval annál hatékonyabb, minél inkább csak a bicepszünket használjuk a gyakorlat közben. Ebben az esetben a könyök fölösleges mozgását vizsgáltuk, mely jól láthatóan eltér. A kék és zöld (z- és y-irányú) gyorsulások az én esetemben (bal oldali) lényegesen kisebbek, mint edzőtársamé (jobb oldali). Megállapítható ezek alapján szabályosabban végeztem a gyakorlatot. Ez a kísérlet is szemlélteti, hogy az eszköz alkalmas arra, hogy egy-egy mozdulatsort pl, sportolóknál korrigáljon, pontosabban rávezessen a helyesebb kivitelezésre, majd monitorozza annak helyességét akár egészen addig, amíg a korrigált mozdulatsor automatikussá nem válik.

21. ábra: Bicepsz mozgások

Továbbá a társam x-irányú (piros) gyorsulásai egy idő után elnyúlnak, ami a fáradást mutatja meg. Ezek alapján optimalizálni lehet a gyakorlatok végzését, melyre az én eszközöm lehetőséget nyújt.

### 4.2.3. Fáradás vizsgálat

Kipróbáltam a szezonalitás-dekompozíció módszerét is, melyet elsősorban gazdasági területen, árfolyamok vizsgálatára szoktak használni. Ez három részre bontja a jelet: egy periodikus jelre, egy trendre, mely a mi esetünkben alkalmas a mozgás jellegének megváltozásának kimutatására, illetve egy maradó hibára.


Végeztünk egy terheléses tesztet, mely esetben az alanynak egy meredek emelkedőn kellett felfele futnia. Ha megjelenítjük a trendet, és illesztünk rá egy egyenest, jól láthatóan egyre rendezetlenebb a járásképe az alanynak.

22. ábra Szezonalitás dekompozíció

Emellett számos érdekes tesztet végeztünk még, de az idő rövidsége miatt csak ezekre jutott időm kielemezni. Munkámat az elkövetkező időben is folytatni fogom.

# 5. Összefoglalás

Ahogy azt az eddigiekben említettem, számos prototípuson és teszten túlvagyunk. Egyre precízebb eszközzel egyre pontosabb adatgyűjtésre vagyok képes, mely bár sosem lesz olyan pontos, mint egy MoCap rendszer, de az egyéb kiemelkedő tulajdonságainak köszönhetően tökéletesen kiegészíti a MoCap hiányosságait.

Adatfeldolgozás esetében újabb teszteket végeztem, illetve újabb módszereket alkalmaztam, de ezt leszámítva jelentős előrehaladás sajnos nem történt.

A jövőre tekintve be szeretném fejezni a saját áramköröm legyártását, továbbá folytatni szeretném a hitelesítést, és végig csinálni a validálási folyamatot. Úgy vélem, mindezt a közeljövőben végig tudom csinálni, melyhez már több labor már felajánlotta segítségét.

# 6. Felhasznált források

1. https://tdk.bme.hu/TTK/NukOrv/Ortopediai-eloszuro-eszkoz-tervezese1 letöltve: 2021.11.07.
2. https://hu.pinterest.com/pin/121456521179677048/?nic_v2=1a7B5hY6M letöltve: 2021.11.07.
3. https://pubmed.ncbi.nlm.nih.gov/16460376/ letöltve: 2021.11.07.
4. https://www.ksh.hu/docs/hun/xftp/idoszaki/elef/te_2019/index.html letöltve: 2021.11.07.
5. BEGG, Rezaul K.; SPARROW, William A. Gait characteristics of young and older individuals negotiating a raised surface: implications for the prevention of falls. The Journals of Gerontology Series A: Biological Sciences and Medical Sciences, 2000, 55.3: M147-M154.
6. https://www.xsens.com/ letöltve: 2021.11.07.
7. https://wearnotch.com/ letöltve: 2021.11.07.
8. http://www.lilygo.cn/claprod_view.aspx?TypeId=21&Id=1282&FId=t28:21:28 letöltve: 2021.11.07.
9. https://www.sparkfun.com/products/16832 letöltve: 2021.11.07.
10. https://wiki.ham.hu/index.php?title=Fourier_transzform%C3%A1ci%C3%B3 letöltve: 2021.11.07.
11. http://astro.u-szeged.hu/oktatas/asztrofizika/html/node92.html letöltve:2021.11.07.

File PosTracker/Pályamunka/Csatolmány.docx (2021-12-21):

A képen rajz látható Automatikusan generált leírás

A képen fű, kültéri, épület, járda látható Automatikusan generált leírás
A képen fű, kültéri, személy, nő látható Automatikusan generált leírás
A képen szöveg, térkép látható Automatikusan generált leírás
A képen szöveg, térkép, rajz látható Automatikusan generált leírás
A képen szöveg, óra, nagyon nagy, fekete látható Automatikusan generált leírás

A képen képernyőkép látható Automatikusan generált leírás
A képen képernyőkép látható Automatikusan generált leírás

A képen képernyőkép látható Automatikusan generált leírás

A képen képernyőkép, madár látható Automatikusan generált leírás



A képen képernyőkép látható Automatikusan generált leírás

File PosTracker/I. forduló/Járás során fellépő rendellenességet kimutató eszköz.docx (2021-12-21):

Az innovatív ötletem egy olyan több részből álló eszköz rendszer, mely képes az emberi járás rendelleneségeinek kimutatására. A kötelező iskolai egészségügyi felmérések során egy ilyen készülékkel lehetőség nyílik a gyors szűrésre, melyet követően, ha szükséges az iskolaorvos a tanulót további ortopédiai vizsgálatokra küldheti.

A lábra ráerősített szenzorokat az alany megadott ideig (ez lehet egy egész nap, de akár csak néhány perc is) magán viseli, miközben hétköznapi dolgait végzi. Ez idő leteltével az addig mért adatokat le tudjuk tölteni a vezérlőről, majd egy hozzá írt programmal grafikus módon megjeleníthető. Az ortopédiában elterjedt standardok és a korábbi szakorvosi vélemények alapján a mérési adatok besorolhatóvá válnak, ha nagy eltérést érzékel a rendszer, akkor ezt jelzi a vizsgálatot végző orvosnak.

Motion Capture segítségével felvett és szakorvos által már megvizsgált járásmintákhoz sikerült hozzáférést kapnom, így magát az eszközt és az összehasonlító és kirajzoló programot kellett elkészítenem.

Az eszköz felépítése:

- Kettő tépőzáras pánttal vádlira erősíthető giroszkóppal és gyorsulásérzékelővel ellátott modul
- Kettő tépőzáras pánttal combra erősíthető giroszkóppal és gyorsulásérzékelővel ellátott modul
- Egy csípőre erősíthető öv, melyen további giroszkóppal és gyorsulásérzékelővel ellátott modulok és a vezérlés található, mely gyűjti, és melyről letölthetők a mért adatok


Az ábrán látható helyeken kell felerősíteni az eszközt tépőzárakkal. A végleges verzió mérete még nem meghatározott, de körülbelül a képen láthatót méret az ideális véleményem szerint.

Ezt az eszközt elsősorban diákok iskolai szűrővizsgálata során lehetne hasznosítani, vizsgálatok időtartamát lehetne vele csökkenteni és a szűrés pontosságát lehetne vele javítani azáltal, hogy hosszas előkészületek és a rendelőben elvégzendő járási gyakorlatok helyett az orvosnak csupán a vizsgált személyre kell erősítenie ezt az eszközt, ezt követően pedig sokkal természetesebb módon, hétköznapi tevékenységei mellett lehet a vizsgálatot elvégezni. Mivel az alany nem a rendelőben lévő járópadon végzi vizsgálatot, hanem hétköznapi környezetben, így valós, a rendelői környezettől és a megfelelési kényszertől nem függő adatokat kapunk.

Járás során fellépő rendellenességet kimutató eszköz Kreinicker Gábor, 12.a Szegedi Radnóti Miklós Kísérleti Gimnázium 29. Ifjúsági Tudományos és Innovációs Tehetségkutató Verseny

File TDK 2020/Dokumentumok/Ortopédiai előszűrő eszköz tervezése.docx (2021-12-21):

Budapesti műszaki és gazdaságtudományi egyetem

Természettudományi kar

Geometria tanszék

Kreinicker Gábor, Sipos Bence

Tudományos Diákköri Konferencia

Ortopédiai előszűrő eszköz tervezése

Konzulens:

Dr. Szilágyi Brigitta

egyetemi docens

Budapest, 2020

TARTALOMJEGYZÉK

# 1. Bevezetés

Napjainkban egyre nagyobb gondot fordítunk egészségünk megőrzésére, ennek okán egyre több figyelem esik testünk megfigyelésére, elég csak az okosóra által gyűjtött véroxigén szaturációra vagy ECG-re gondolni. A mozgásunkat is sok esetben monitorozzuk GPS vagy egy egyszerű lépésszámláló segítségével. Ennek ellenére a járásunkra, futásunk pontos mechanikájára nem figyeljük eléggé. Igaz, ennek oka lehet a rendelkezésre álló eszközök szűkössége is, ellentétben a korábbi példákban említett paraméterek megfigyelésére alkalmas eszközök bőséges választékával.

A nem megfelelő mozgás miatt kialakuló szövődmények pedig sok ember életét keserítik meg, viszont a jelenlegi szűrés csak az igazán súlyos esetek válogatására alkalmas, pontos vizsgálatokat, mint amilyen egy Motion Capture (MoCap) felvétel csak indokolt esetekben végeznek, mivel a vizsgálható személyek száma alacsony és a vizsgálathoz szükséges gépek nagyon költségesek.

A MoCap egy laborhoz kötött mozgásrögzítő rendszer. A vizsgálata elején a páciensre markereket helyeznek, amiket több, a terem különböző részein elhelyezett kamera követ. Mivel a kép kétdimenziós, így egy pont helyének meghatározásához legalább három kamera képe kell, melyből szoftveresen meg lehet határozni a pont térbeli helyét.

Jelen dolgozatban a célunk egy olyan rendszer megalkotása volt, ami nagy tömegben képes előszűrni a járásproblémákat, hosszan, különböző körülmények között képes megfigyelni a páciens mozgását. Mindezek ellenére a járáslaborok kiváltása nem cél, mivel a pontos kvantitatív vizsgálatok elvégzése csak azokban lehetséges.

A járáslaborok nagy hátránya, hogy korlátos méreteik miatt (általában néhány méter), csak egy kis időszeletet vizsgálnak, nincs a legtöbb esetben lehetőség arra, hogy kilométereket tegyenek meg a vizsgált páciensek. A másik probléma a vizsgálat rövidségével, hogy így nem feltétlenül a természetes mozgását végzi a vizsgált személy, mivel tudja, hogy meg van figyelve. (Fehér köpeny effektus.) A mérés hosszának növelésével és a mozgás természetes környezetben való megfigyelésével reményeink szerint egy átfogóbb kép kapható, továbbá kiszűrhetők például a fáradás vagy éppen a vércukorszint ingadozás következtében fellépő elváltozások is. A mért adatok megfelelő módon történő továbbítása esetén lehetőség adódik arra is, hogy egy edző vagy egy sportorvos távolról segítse a tanítványát, páciensét.

Tehát az eszközzel a célunk egy hosszabb megfigyelés lehetőségének megalkotása volt, egy 24 órás vérnyomásméréshez (ABPM) vagy egy Holter-monitorhoz hasonlóan. Emellett a cél a könnyű kezelhetőség és felszerelhetőség, hogy egymás után sok személyt lehessen vele mérni, minél kevesebb állítással. Ez főleg iskolai vagy sportorvosi szűrővizsgálatok során lehet nagyon hasznos, ahol sok mozgást kell megfigyelni viszonylag rövid idő alatt. Az eszköz lehetőséget nyújthat a betegek rehabilitációjának nyomon követésére, ahogy a sportolók különböző terhelés folyamán történő, akár rendszeres megfigyelésére, a kapott eredmények összehasonlítására is.

Bár most eszközünk járásvizsgálatban való alkalmazását mutatjuk be, természetesen egyéb mozgások analizálásában is szerepet kaphat. Másik fontos alkalmazási terület lehet a sportolók mozgásának megfigyelése, ahol nemcsak a problémák kiszűrése jöhet szóba, hanem egy-egy mozgásforma finomítása, a helyes technika elsajátítása is.

# 2. Szakirodalmi áttekintés

A szakirodalmi áttekintés két részre bontható: a járással kapcsolatos problémák és az általunk készített kiértékelés módszereinek bemutatására.

## 2.1. Járásproblémák

Az egészséges járáshoz három szükséges és elégséges feltételnek kell teljesülnie: megfelelő erőbefektetés, megfelelő koordináció és megfelelő érzékelés. Járásszervi elváltozásról akkor beszélhetünk, ha ezek közül legalább az egyik nem teljesül, ugyanis ekkor felborul a járáskép. Járási rendellenesség kialakulásának okai lehetnek genetikai tényezők, betegségek, sérülések vagy elváltozások az alsó végtagban.

Öt típusú elváltozást különítünk el [1]: van az ún. bénult járás (spastic gait), amikor az alany a földön végig húzva a lábát jár. Emellett van az ollózás (scissors gait), ekkor a lábfejek egymás felé vannak fordulva. A lábejtés (steppage gait) során az alany járás közben lábujjhegyét végighúzza a talajon. Vándorgó járás (vaddling gait) esetén az alany oldalirányba nagy kilengéseket tesz felső testből. Az ötödik az előre hajló járás (propulsive gait), ekkor az alany előre dőlve halad. A fent említett elváltozásokat az 1. ábra szemlélteti.


1. ábra Járásproblémák [2]

A KSH egy 2019-ben készült, a magyar lakosságon végzett egészségfelmérése alapján azt mondhatjuk, hogy a magyar felnőttek negyede nem mozog megfelelően, amely elgyengült izomzathoz, rossz tartáshoz és később járáshibához vezethet, ami további, súlyosabb betegségekhez vezethet. A járásszervi elváltozások szűrésének elmaradottságára utal, hogy szintén ezen kiadvány szerint, minden ötödik magyar felnőttnek okoz valamekkora nehézséget a járás. Az általuk elszenvedett problémák egy része megfelelő szűrés esetén megelőzhető lehetne.


2. ábra KSH adatai a járásproblémákkal rendelkezőkről [3]

A járáshibák diagnózisát jelenleg a páciensek egészségügyi anamnéziséből és rövid távon megvizsgált járásából állítják fel, ritkán további laborvizsgálatokra küldik a problémás pácienseket a szakorvosok. Ez a folyamat sok időt vesz igénybe és egyszerre általában egy páciens szűrése végezhető csak. Az általunk fejlesztett eszköz ehhez próbál kiegészítést adni.

Ugyan jelenleg a piacon több hasonló eszköz is jelen van, azonban azok teljesen ki akarják szorítani a MoCap rendszereket. Továbbá a most rendelkezésre álló eszközök zömében nagyon drágák is, ami szintén gátolhatja a tömeges szűrés megvalósítását. Emellett kötöttségük okán alacsony testre szabási lehetőséget nyújtanak.

Az ilyen eszközök a Nansenseansense Suits [4], a Notch [5], vagy a Sens motion [6]. Ezek mind a mienkéhez hasonló mintavételezési idővel rendelkeznek.

## 2.2. Feldolgozó módszerek

A rendszer felépítésének bemutatása a fejlesztések fejezetben részletesen kifejtésre kerül, az adatok feldolgozásához használt módszerek bemutatása előtt viszont fontosnak tartjuk megmutatni, hogy milyen mért értékekkel dolgoztunk. A méréseket 7 szenzorral rögzítettük, mindegyik szenzor 3 gyorsulásértéket adott vissza (x, y és z tengely irányában). Emellett lehetséges még a giroszkóp adatait is vizsgálni, de a mágneses terekről is van információnk. Az adatok a szenzorokból megközelítőleg 120 Hz-en érkeznek, tehát kevés idő alatt viszonylag nagy mennyiségű adatot vagyunk képesek gyűjteni.

### 2.2.1. Adatok vizualizációja

Ahhoz, hogy a mért adatokat jobban megérsük szükséges az adatok vizualizációja. A lábbal páhuzamos gyorsulások értékei jól szemléltethetők az idő függvényében, de a mozgás síkjára merőlegesen mért értékeknél már nem ilyen egyszerű a helyzet és csak frekvencia tartományban láthatóak jól a jelek.

A járás jó közelítésben periodikus, de a periódus hossza széles tartományban változhat. Az egyes periódusok egymással történő összehasonlításával a ritka, de annál érdekesebb események megkaphatóak, ehhez viszont a jelet lépésekre kell bontani. A felbontásra több lehetőség is van, az egyik a lokális szélsőértékek keresése, a másik pedig az autokorreláció [7].

A periodikus jelek vizsgálatának kézenfekvő módszere a frekvenciatartományba való átlépés. Erre is két fő lehetőség van, az egyik a Fourier-transzformáció, a másik pedig a wavelet-transzformáció. Az egyszerű Fourier-transzformáció esetén a teljes jelet egyben vizsgáljuk, tehát az időbeli változásokat elveszítjük. Ez viszont egy fontos paraméter lehet, például a fáradás elemzésekor. Ennek kezelésére a Short-time Fast Fourer Transformation ad módot, ahol egy mozgó ablakban végzünk FFT-t, így megismerve ezen rövid szakaszok spektrumát.

A másik lehetőség a wavelet transzformáció [8], ahol egy wavelet sereggel söprünk végig az adatokon, így megkapva az egyes frekvenciák amplitúdóját. A 3. ábrán igen jól látszik, hogy mi a wavalet előnye: az eltérő frekvenciákon eltérő a felbontása, miközben az STFT-nál ez nem így van.

Use of Wavelet and Fast Fourier Transforms in Pharmacodynamics | Journal of Pharmacology and Experimental Therapeutics

3. ábra STFT és wavelet összehasonlítása [8]

A frekvenciatartományban jól látszódnak a mozgás sebességének változásai, de ezt a vizsgálatainkat taglaló részben bővebben bemutatjuk.

### 2.2.2. Periodikus jelek vizsgálatára használt módszerek

A periodikus jelek esetén sok esetben lehetséges a jeleket két csoportra bontani, egy általános trendre és egy periodikus részre. Ezt seasonal decompositonnek [9] szokták nevezni az adatfeldolgozás területén és nagyon sok helyen használják.

A legegyszerűbb megoldás mindössze mozgóátlagokat használ és már ezekkel is használható modellek alkothatók a mozgóablak méretének jó meghatározásával. Léteznek ennél sokkal kifinomultabb módszerek is, mint például a lokális polinomregressziót használó STL módszer.


4. ábra Szezon dekompozíció [9]

A szétválasztott jelek vizsgálatával lehetséges a hosszabb távú változások vizsgálata, ami főleg hosszabb mérések esetén lehet érdekes számunkra.

### 2.2.3. Adatok anomáliainak detektálása

A mérések hibákkal terheltek, számos esetben előfordulnak olyan kiugró értékek, melyek fizikailag nem lehetségesek vagy az addig követett trendtől nagyon eltérnek. Ezek szűrése történhet egy egyszerű mediánszűréssel, azonban, ha nem szeretnénk sok információt veszteni, akkor használhatunk kifinomultabb eszközöket is, mint például egy DBSCAN alapú detektáció. Itt a DBSCAN klaszterező eljárást használjuk arra, hogy a nagyon kiugró adatokat eltávolítsa a méréseinkből [10].

Mivel az adataink periodikusak, ezért statisztikai módszerekkel létrehozhatunk egy sablont, amivel a kiugrásokat szűrhetjük. Ehhez egy konfidenciaintervallumot definiálunk és az ezen kívül eső pontokat elhagyjuk vagy valamilyen módszerrel helyettesítjük. A módszer hibája, hogy előfordulhatnak a vizsgálat során olyan esetek, amikor megváltozik a mozgás, de az nem a mérési hibából adódik, ilyen helyzet például járás közben egy lépcsőre való fellépés.

Ha hosszú időn keresztül rögzítjük az adatokat, akkor arra is van lehetőség, hogy az egyes lépéseket klaszterezzük és a nagyon kis elemszámú klasztereket elhagyjuk vagy manuálisan vizsgáljuk. Ezzel a módszerrel a pillanatszerű hibák nem szűrhetők, de egy hosszabban feltálló mérési hiba detektálható Ilyen hiba lép fel a szenzor lecsúszásakor, elfordulásakor.

A korábban bemutatott dekompozíció is alkalmas lehet a hibák megtalálására, mivel ahol nem képes jól előre jelezni a mintát, ott jó eséllyel problémás adat lehet. Ennél pontosabb és kifinomultabb módszerek regressziós fákat használnak az anomáliák észlelésére [11].

### 2.2.4. Idősorok osztályozása

Az idősorok osztályozása az élet számos területén fontos, a beszédfelismeréstől a gazdasági adatok elemzéséig, hogy csak néhányat emeljünk ki. Ezért a szakirodalom nagyon sok lehetőséget kínál az adatok feldolgozására.

Az egyik legelső nagy áttörést hozó módszer az LSTM (Long short-term memory) volt, ami a 1990-es évek közepén jelent meg, de csak 2010 környékén kezdett elterjedni. Az ezt követő 6-7 évben az idősorok feldolgozásában az egyik vezető megoldás volt, mára viszont az újabb módszerek a háttérbe szorították [12]. A visszacsatolt hálók családjába tartozik, mivel található benne visszacsatolás, az egyszerű visszacsatolt hálókhoz képest bír azzal a nagy előnnyel, hogy nem jelenik meg a vanishing gradient problémája, ami a tanításkor jön elő és a mélyebben lévő rétegek tanulását nehezíti meg. Az elmúlt években az LSTM cellák azért kezdtek háttérbe szorulni, mert használatuk kevésbé gyorsítható, mint az újabb módszereké, ennek ellenére még mindig érnek el vele nagyon jó eredményeket [13].

Az mindennapi használati eszközökön futó gépi tanuló modellek miatt egyre nagyobb az igény a jól optimalizálható módszerekre, melyek képesek magas pontosságot biztosítani kisebb erőforrások mellett. Ezek miatt indult el a 1D konvolúció használata, ami jól gyorsítható hardveresen és nagyon magas pontosságokra képes. Az 1D konvolúciós hálók segítségével lehetséges az emberek tevékenységét meghatározni mindössze gyorsulásszenzor adatok alapján. A mi feladatunk ehhez nagyon hasonló, annyi eltéréssel, hogy nem egyetlen csatorna alapján kell csak a számításainkat végezni, hanem 7 szenzorból jönnek az adatok. A módszerrel elért magas pontosság és az egyszerű futtathatóság lehővé teszi akár az offline alkalmazását is a módszernek, tehát nincs szükség arra, hogy az adataikat egy szerverre eljuttassuk [14].

A jelek feldolgozásának további lehetősége a jelek STFT-jének vizsgálata. Itt már az egydimenziósból kétdimenziós adatot készítünk és ezt főleg a képfeldolgozás területén elterjedt 2D konvolúciós hálókkal tudjuk feldolgozni.

# 3. Eszköz felépítése és működése

MPU-9250részből épül fel. Az első rész 7 MPU9250-es 9 szabadságfokú szenzorból épül fel, melyek közül 2 a combokon, 2 a lábszárakon, 2 a lábfejeken, végül pedig 1 a derékra van rögzítve. A másik rész végzi a szenzoradatok olvasását, mentését és az adatok szerverre való továbbítását.


5. ábra A rendszer felépítése

## 3.1. Szenzorok és azok rögzítése

### 3.1.1. MPU-9250

A mérést végző szenzornak az MPU9250 típusú, 9 szabadsági fokú szenzort (3 tengelyű gyorsulásmérő, giroszkóp és magnetométer) választottuk, mivel kis mérete és tömege által kellően kényelmes viselni ahhoz, hogy ne befolyásolja a mérés eredményeit és ne akadályozza viselőjét mozgás közben. Emellett költséghatékony és sokoldalú, mely utóbbi a továbbfejlesztések során játszik majd nagyobb szerepet.

Minden szenzor olvasásához öt kivezetést használunk. Kettőn az áramellátást kapja meg, kettőn kommunikál a vezérléssel és az ötödiken tudjuk megváltoztatni állapotát.

A mérés során sikerült 120 Hz feletti frekvenciával olvasni a szenzorokat, de mivel egy I2C buszra vannak felfűzve és mindössze 2 cím adható a szenzoroknak, ezért szükséges a cím változtatása 2-nél több szenzor esetén. A mérés során a 0x68-as címről olvastunk, ami a címválasztó láb alacsony értéke esetén aktív, a lábra magas jelet kapcsolva a szenzor a 0x69-es címre vált. Ezt használtuk ki és léptettük végig ezt az alacsony jelszintet az egyes szenzorokon, hogy pontosan egy maradjon csak a 0x68-as címen az olvasáshoz. Ezzel a módszerrel sajnos vesztünk az elméleti maximális mintavételezési frekvenciából, de így nincs szükség kettesével egy további mikrokontrollerre.

### 3.1.2. CAD tervek és megvalósítása

Ezek közül az érzékelők közül hat a következő módon helyezhető fel a lábra: kaptak egy Fusion 360-ban megtervezett, 3D nyomtatóval kinyomtatott tokozást, amelyen keresztül fut egy gumi gyűrű. Ebbe kell az alanynak belehelyeznie a lábát. A gumigyűrűn elhelyezkedik egy elosztó, amely az előző szenzortól érkező, a következő szenzorhoz vezető és az aktuális szenzor vezetékeit megfelelő módon elosztja.


6. ábra A CAD modell és a nyomtatott szenzortartó

A végtagokon elhelyezkedő szenzorok vezetékei egy derékszíjon elhelyezett tokba futnak bele, amelyben kettő Arduino nano, egy Raspberry Pi, a hetedik MPU szenzor és egy akkumulátor helyezkedik el.

## 3.2. Központi egység

### 3.2.1. Arduino

A mérést két Arduino Nano végzi, mivel kis méretű, tömegű és költséghatékony. A következő módon osztják meg az érzékelőket: az egyik mér az egyik lábon levő három szenzorral, a másik a másik lábon levő három szenzorral és a derék közepén levő szenzorral. (7. ábra) Emiatt lehetne eltérés a két mikrokontroller mintavételezési ideje között, de ezt szoftveresen ki tudtuk küszöbölni.

Az Arduinok I²C buszon keresztül kommunikálnak az érzékelőkkel. Mivel egyszerre csak egy szenzor olvasását tudjuk elvégezni, így egy izgalmas megoldáshoz folyamodtunk. Egy szenzor két állapotban lehet: alvó állapotban, amikor 0x68 címen érhető el és aktív állapotban, amikor 0x69 címen érhetjük el. Bármely érzékelőt tetszőlegesen tudjuk váltogatni e két állapot között.

A vezeték nélküli kommunikációért egy Raspberry Pi 4 B típusú mikroszámítógépet használtunk, mely se nem kicsi és könnyű, se nem költséghatékony, azonban ez rendelkezett olyan specifikációkkal, ami alkalmas megfelelő gyorsasággal és mennyiségben továbbítani az adatot. Az Arduinokkal soros porton keresztül kommunikál. A befolyt adatot a Pi 4 GB CSV (Comma-separated values) fájlba kimenti és továbbítja az előre kijelölt számítógépre.

Jogosan merül fel a kérdés, miért nem egyetlen mikrokontrolleren vagy mikroszámítógépen végezzük mind a mintavételezést, mind pedig a továbbítást. Ennek oka, hogy nem lehetséges a szenzorok megfelelő címzése, a címzésből adódó nehézségek pedig egy olvasó eszközt használva nagyon lassúvá tennék a mérést.


7. ábra A szenzorok helye a lábon

## 3.3. Méréseink

A célunk elsődlegesen az eszköz megalkotása volt, valamint az, hogy jó módszereket találjunk az adatok feldolgozására. Ezért nem végeztünk kiterjedt méréseket sok ember bevonásával. Erre a pandémia miatt nem is lett volna módunk. Próbáltunk olyan adatokat gyűjteni, amik egy általános felhasználás esetén fordulnak elő, de végeztünk tesztet arra is, hogy a futás során milyen változások lépnek fel a sportoló fáradásával. Ezen méréseink közül fogunk néhányat bemutatni.

### 3.3.1. Átlagos járás

Ezen mérés során egy 150 méteres mintát rögzítettünk, amely alatt a mérésben részt vevő személy 2 darab 180 fokos fordulatot is végzett, ami jól látszik a wavelet tanszformálton. A fordulás a 37 és a 94 másodperc környékén volt, ahol a járás üteme megváltozott, érdekes módon nem lassult, hanem ellenkezőleg kissé gyorsabb lett.


8. ábra A jobb comb z irányú gyorsulásának wavelet transzformáltja

A láb egyes részeinek gyorsulásai is jól bemutathatóak ezen az adaton. Ehhez az 59,5 és 64,7 másodperc közti részt használtuk, ahol egyenletesen haladt a vizsgált személy. Ha csak a comb és a lábszár gyorsulását nézzük, akkor jól látszik, hogy a kettő szinte teljesen együtt mozog (9. ábra), ami azt is jelentheti, hogy ha csak a gyorsulásokat vizsgáljuk elég az egyiknek a mérése.


9. ábra Szenzorok gyorsulásainak összehasonlítása

A lábfej gyorsulását együtt ábrázolva a másik két jellel, jól látszik, hogy óriási az eltérés, jóval nagyobb gyorsulások érik az ember lábfejét, mint a combját vagy a lábszárát.

A jel vizsgálható autokorrelációval is, ahol azt kaptuk, hogy 92 mintányira ismétlődik a jel, ami 120 Hz-es mintavételezéssel 1,3 lépést jelent másodpercenként. A gyorsulás grafikon csúcsait leolvasva is ezt az értéket kapjuk, illetve, ha a lokális szélsőértékeket nézzük, ott is ez adódik.


10. ábra Az autokorreláció és a lokális szélsőérték-keresés eredménye

### 3.3.2. 15 fokos (27%-os) emelkedőre való futás

Ezt a mérést egy futógépen végeztük 15 fokos (27%-os) emelkedéssel, így csökkentve a méréshez szükséges időt, mivel a vizsgált személy gyorsabban fáradt el. Itt a periodikus jel mögötti trendre voltunk kíváncsiak.

A dekompozíciót követően a trendvonal vizsgálata megmutatja, hogy egyre lennebb kerül a trend, ami azt jelzi, hogy futás közben az átlagos gyorsulás egyre jobban csökkent a combon. Emellett jól látszik az is, hogy egyre szélesebb a vizsgált sáv, ami azt jeleníti meg, hogy egyre kevésbé szabályos a futás, amit a fáradás számlájára írhatunk.


11. ábra A dekompozíció során kapott trend és az erre illesztett görbe

Az általunk készített prototípus több óráig képes az adatok mentésére. Ezért később lehetséges akár több órán keresztül vizsgálni a fáradást. Azonban már egy ilyen rövid, de nagy terhelés alatt is jól látszik, hogy a fáradás miatt a mozgás kissé rendezetlenebbé válhat, ami indokolhat egy hosszabb megfigyelést, ezzel alátámasztva a mérés létjogosultságát.

### 3.3.3. Egészséges ember járása a két lábon eltérő talpvastagságú cipőben

Végeztünk egy mérést arra vonatkozóan, hogy 4 mm-es cipőtalp-vastagság különbség miként jelenik meg a járás mintájában. Két azonos márkájú, de eltérő talpvastagságú cipőben sétáltattunk a megfigyelt személyt, annak vizsgálatára, hogy miként változik meg a járásának a képe ahhoz képest, amikor azonos talpvastagságú cipőt visel. A két láb mozgása a beolvasott jelek alapján nem mutatott nagy eltérést, itt a cél inkább az volt, hogy adatot generáljuk egy hibás járásról a gépi tanuló algoritmusoknak.


12. ábra Azonos és eltérő cipők viselése mellett a jobb comb gyorsulásai

### 3.3.4. Gyaloglás cipőben és mezítláb

Ennek a mérésnek a célja a láb gyaloglás során történő gyorsulásainak vizsgálata volt. Annak érdekében, hogy a legnagyobb sebességgel tudjuk olvasni a szenzort, mindössze egy combon elhelyezett eszköz gyorsulás és giroszkóp értékeit rögzítettük. Ezzel lehetővé téve, hogy a kisebb időköz miatt a nagyobb kiugrásokat is jót tudjuk detektálni.

Minden igyekezet ellenére jól látszik az 12. ábrán, hogy nem azonos magasságúak a csúcsok, bár egyenletesnek tűnt a vizsgált személy mozgása. Ahhoz, hogy a környezet hatását kizárjuk ezt a mérést futópadon végeztük, és csak a mérés közepéből való adatokat vizsgáltuk, tehát a futópad megszokásától és a fáradástól is el lehetett tekinteni. Emiatt gondoljuk úgy, hogy az eltérő értékek hátterében a szenzor integrálási ideje állhat. Ami még jól látszott, hogy ezeket a mérési adatokat összehasonlítva a korábbi mérésekkel, magasabb csúcsok voltak, annak ellenére, hogy ott is ugyanazt a személyt mértük azonos lábbeliben. Ez is az integrálási idővel kapcsolatos teóriánkat támasztja alá. További bizonyíték erre, hogy a csúcsok periodikusan változnak, ami akkor szokott előfordulni, ha a mért jel és a mintavételezés frekvenciája egymásnak közel egészszámú többszöröse, de ezen egészhez képest van egy nagyon kis eltérés, ami megjelenik a csúcsok periodikus változásának frekvenciájában.


13. ábra A comb z irányú gyorsulás

A mérés során egy futócipők között közepesnek mondható talpvastagsággal rendelkező Nike Zoom Gravity (31/21 mm talp) cipőt hasonlítottunk össze a mezítlábas adatokkal. Az n. ábrán tátható, hogy a combot érő gyorsulás alacsonyabb mezítláb, legalábbis a z tengely irányában, a többi tengely esetén ez fordítva van. Ez igen érdekes, valószínűleg ennek oka az óvatosabb járásban keresendő. A csúcsok átlagát nincs sok értelme nézni, mivel a korábban bemutatott mintavételezési probléma miatt nem igazán jól mutatja a valóságot.

Azért, hogy valamilyen módon mégis számszerűsíteni tudjuk a maximumokat, a csúcsok felső 10%-át átlagoltuk. A cipőben történő mozgás esetén 26,45 [m/s²], mezítláb pedig 34,26 [m/s²] gyorsulásértékek adódtak.


14. ábra Cipőben történő és cipő nélküli gyaloglás során fellépő erők

Az 13. ábrán jól látszik, hogy a görbék lefutása hasonló. Az egyedüli jól kivehető különbség a két mintázat között - a maximális gyorsulást leszámítva -, a lépésciklus 60%-a környékén lévő második nagy gyorsulási időben való eltolódása és erőteljesebb megjelenése a cipő használata esetén.

## 3.4. Gépi tanulás alapú osztályozás

Jelen fejezetben tárgyalt módszerek az egyes mérések feldolgozási lehetőségeit mutatják be. Mivel kis mennyiségű adaton futtattuk őket, a velük kapott eredmények pontossága egy valós felhasználáshoz képest eltérhet.

A normál járás és a mezítláb történő járás adatait osztályoztuk 1D konvolúcióval és LSTM hálóval, a 2D konvolúciót használó hálót pedig egy többszenzoros mérés adataival tanítottuk és teszteltük.

Az első két módszerhez az adatokat a n. ábrához hasonlóan készítettük elő, tehát a maximumok közti részt interpolációval azonos hosszra alakítottuk, ezt követően pedig normalizáltuk a mintákat, hogy a hálók tanítására lehessen használni.

A 2D konvolúció esetén más módszert alkalmaztunk, az adatok wavelet transzformáltjával dolgoztunk. Így a kezdetben egydimenziós adatot egy idő és egy frekvencia síkra alakítottuk át. Ehhez a Scipy CWT függvényét használtuk az adatok teljes hosszában, és ezután egy mozgó ablakkal daraboltuk a létrejött, igen hosszú mátrixot. A darabolás eredménye a 13. ábrán látható. A mozgóablakolással mindössze néhány perc mérésből 1800 mintát lehet generálni. Azért volt szükség a teljes mérés adatait egyben kezelni, mivel, ha a szeletelt jelet transzformáltuk volna, akkor a minták végén lévő bizonytalanságok hibát vittek volna a mérésbe, egyben kezelve, viszont ezt a hibát minimalizálhatjuk a memóriafelhasználás kárára.


15. ábra A comb z irányú gyorsulásának wavelet transzformáltja

### 3.4.1. LSTM

Az azonos hosszra alakított adatokat egy igen egyszerű LSTM hálóval próbáltuk feldolgozni, mindössze 4 LSTM blokk felhasználásával. Azért törekedtünk itt az egyszerűségre, mert így a méréshez használt Raspberry Pi-n is lehet tanítani vagy épp alkalmazni a betanított modellt és predikciókat generálni. A több bemutatott modell esetén ennél kissé nagyobb az erőforrásigény, de ezek is futtathatóak offline, akár valós időben például egy Coral USB gyorsító segítségével. (A valós idejű vizsgálatok főleg sportolásnál lehetnek érdekesek, mivel ezek segítségével nyomon követhető a fáradás, akkor is, ha azt még nem is érzékeljük.)

### 3.4.2. 1D konvolúciós háló

Az 1D konvolúció futtatásához egy már bevált hálót alkalmaztam, amivel emberek tevékenységeit osztályozták gyorsulásadatok alapján. A futás során viszont kiderült, hogy a mért értékeink 2 csatorna esetén megegyeznek, így nagyban torzítják a pontosságot. Emiatt vagy más okból, a pontosság csak 56% lett a tesztadatokon, ami nem sokkal jobb, mintha a háló véletlenszerűen sorolta volna be az adatokat [15].

Az alacsony pontosság másik oka lehet még a kevés adat. Az adatok gyűjtésén folyamatosan dolgozunk, hogy minél pontosabb modellt tudjuk később építeni.

### 3.4.3. 2D konvolúció

Ennek a hálónak a tanítására wavelet transzformált adatokat használtunk egy korábbi, alacsonyabb mintavételezésű mérésünket feldolgozva. A háló 2 konvolúciós réteget, egy dropoutot és egy dense kimeneti réteget tartalmaz. Ennek a modellnek a futtatásakor is azzal kellett szembesülni, hogy ahhoz, hogy jobb eredményeket érjünk el, sokkal több adatra lenne szükségünk.

Egy megközelítőleg 4 másodperces szakasz futtatása egy Nvidia K80-as GPU segítségével, áltagosan 156 ms-volt, ami azt jelenti, hogy az előkészítéssel együtt is, a mérés hosszának töredéke alatt elkészíthető a kiértékelés. (Ez főleg akkor fontos, ha több óra adatát szeretnénk feldolgozni.)

### 3.4.4. Umap

A gépi tanuláshoz készített adathalmazon könnyen futtathatunk például egy Umap dimenzióredukciót, hogy meglássuk, hogy az egyes csoportokon belül mekkora az adatok közti hasonlóság. A 15. ábrán jól elkülönülnek a csoportok, de az is látszik, hogy néhány pont átkerült a másik csoporthoz. Ha ezeket közelebbről megvizsgáljuk, azt tapasztaljuk, hogy ezek voltak azok az adatok, amik a csoport egyben ábrázolásakor egészen messze voltak az átlagtól, így érthető, hogy az algoritmus nem tudta megfelelően besorolni őket.


16. ábra Lépések Umap-ja

### 3.4.5. A módszerek összehasonlítása

A hálók felépítései a 16-es ábrán láthatóak. Jól látszik, hogy mennyire rövid az LSTM háló felépítése. Azonban ez nem szabad, hogy megtévesszen minket, mert az LSTM blokkok számítása időigényesebb lehet, mint egy konvolúció.


17. ábra LSTM, 1D és 2D konvolúciós háló

Futásidőben hatalmas különbségek adódtak, mert amíg egy lépést az LSTM háló 5ms alatt képes feldolgozni, addig az 1D konvolúciónak ehhez csak 3ms-ra van szüksége, a 2D esetben 156 ms-ot tölt a program megközelítőleg 4 lépéshez szükséges idő feldolgozására, de így is ez a leglassúbb, nem beszélve az előkészítés idejéről. Az elért pontosságról sok értelme nincs beszélni ilyen kevés tanítóadat esetén, de úgy tűnik, hogy az LSTM már ilyen kevés adat alapján is 78.95%-os pontosságot tudott elérni a teszt adatokon, miközben a másik két módszer csak néhány százalékkal tudott többet egy véletlen választáshoz képest.

# 4. ÖSSZEFOGLALÁS és A továbbfejlesztés lehetőségei

Az eszköz jelenleg vezetéken keresztül kommunikál a vezérléssel, amely elhagyható lehet vezetéknélküli (bluetooth vagy wifi) kommunikáció és szenzoronkénti akkumulátor használatával.

Erre alkalmas lehet a Lilygo TTGO [17] nevű eszköz. Ez tartalmaz akkumulátort, gyorsulást- és szögelfordulást mérő érzékelőt és vezeték nélküli kommunikációra alkalmas modult. Minden eszköz wifin keresztül tudna kommunikálni a vezérléssel, hasonló mintavételezési idővel, de a kapcsolgatásokból származó időelcsúszás nélkül.


18. ábra Lilygo TTGO

Emellett az eszköz ruhára való felhelyezése helyett lehetne készíteni olyan ruhákat, melyek már tartalmazzák a mérő rendszert. Léteznek felvarrható gyorsulást és szögelfordulást mérő érzékelők, ilyenek a MbientLab [18] és MetaMotion [19] szenzorok. Ez is javítaná a mérés kényelmét.

További fejlesztési lehetőség lenne, ha reverzibilissé tennénk az adatforgalmat. Elképzelhetőnek tartjuk, hogy az olvasott jelek alapján valós időben járást korrigáló jelet küldjünk vissza az adott testrészre. Ez történhet ingert kiváltó elektromos impulzussal, de akár egy mechanikus rendszerrel is. Ezzel lehetne gyorsítani a tanulást vagy a rehabilitációt. Ez természetesen történhet vizuális visszacsatolással is.

# 5. Felhasznált források

1. https://www.medicalnewstoday.com/articles/320481#types, 2017.12.31.
2. https://hu.pinterest.com/pin/121456521179677048/?nic_v2=1a7B5hY6M
3. https://www.ksh.hu/docs/hun/xftp/idoszaki/elef/te_2019/index.html
4. https://www.nansense.com/suits/, 2020.10.28.
5. https://wearnotch.com/, 2020.10.28.
6. https://sens.dk/, 2020.10.28.
7. NELSON-WONG, Erika, et al. Application of autocorrelation and cross-correlation analyses in human movement and rehabilitation research. journal of orthopaedic & sports physical therapy, 2009, 39.4: 287-295.
8. MAGER, Donald E.; ABERNETHY, Darrell R. Use of wavelet and fast Fourier transforms in pharmacodynamics. Journal of Pharmacology and Experimental Therapeutics, 2007, 321.2: 423-430.
9. R. B. Cleveland, W. S. Cleveland, J.E. McRae, and I. Terpenning (1990) STL: A Seasonal-Trend Decomposition Procedure Based on LOESS. Journal of Official Statistics, 6, 3-73.
10. Li H, Wang W, Huang P, Li Q. Fault diagnosis of rolling bearing using symmetrized dot pattern and density-based clustering. Measurement. 2020 Feb 1;152:107293.
11. SALEM, Osman, et al. Sensor fault and patient anomaly detection and classification in medical wireless sensor networks. In: 2013 IEEE international conference on communications (ICC). IEEE, 2013. p. 4373-4378.
12. GERS, Felix A.; SCHMIDHUBER, Jürgen; CUMMINS, Fred. Learning to forget: Continual prediction with LSTM. 1999.
13. https://deepmind.com/blog/article/alphastar-mastering-real-time-strategy-game-starcraft-ii
14. LEE, Song-Mi; YOON, Sang Min; CHO, Heeryon. Human activity recognition from accelerometer data using Convolutional Neural Network. In: 2017 ieee international conference on big data and smart computing (bigcomp). IEEE, 2017. p. 131-134.
15. CHO, Heeryon; YOON, Sang Min. Divide and conquer-based 1D CNN human activity recognition using test data sharpening. Sensors, 2018, 18.4: 1055.
16. HASAN, C. Z. C.; JAILANI, ROZITA; TAHIR, N. M. Automated classification of gait

abnormalities in children with autism spectrum disorders based on kinematic

data. Int. J. Psychiatry Psychother, 2017, 2: 10-15.

17. http://www.lilygo.cn/claprod_view.aspx?TypeId=21&Id=1282&FId=t28:21:28, 2020.10.28.
18. https://mbientlab.com/metamotionc/, 2020.10.28.
19. https://metamotion.com/, 2020.10.28.

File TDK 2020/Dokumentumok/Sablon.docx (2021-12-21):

BME

Budapesti műszaki és gazdaságtudományi egyetem

Természettudományi kar

Geometria tanszék

Kreinicker Gábor, Sipos Bence

Tudományos Diákköri Konferencia

Ortopédiai előszűrő eszköz tervezése

Konzulens:

Dr. Szilágyi Brigitta

egyetemi docens

Budapest, 2020

TARTALOMJEGYZÉK

# 1. Bevezetés

Nagyjainkban egyre nagyobb gondot fordítunk egészségünk megőrzésére, ennek okán egyre több figyelem esik testünk megfigyelésére, elég csak az okosóra által gyűjtött véroxigén szaturációra vagy ECG-re gondolni. A mozgásunkat is sok esetben monitorozzuk GPS vagy egy egyszerű lépésszámláló segítségével. Ennek ellenére a járásunkra, futásunk pontos mechanikájára nem figyeljük eléggé. Igaz, ennek oka lehet a rendelkezésre álló eszközök szűkössége is, ellentétben a korábbi példákban említett paraméterek megfigyelésére alkalmas eszközök bőséges választékával.

A nem megfelelő mozgás miatt kialakuló szövődmények pedig sok ember életét keserítik meg, viszont a jelenlegi szűrés csak az igazán súlyos esetek válogatására alkalmas, pontos vizsgálatokat, mint amilyen egy MoCap felvétel csak indokolt esetekben végeznek, mivel a vizsgálható személyek száma alacsony és a vizsgálathoz szükséges gépek nagyon költségesek.

A dolgozatban a célunk egy olyan rendszer megalkotása volt, ami nagy tömegben képes előszűrni a járásproblémákat, hosszan, különböző körülmények között képes megfigyelni a páciens mozgását. A járáslaborok kiváltása nem cél, mivel a pontos kvantitatív vizsgálatok elvégzése csak azokban lehetséges.

A járáslaborok nagy hátránya azonban, hogy csak egy kis időszeletet vizsgálnak, nincs a legtöbb esetben lehetőség arra, hogy kilométereket tegyenek meg bennük a vizsgált páciensek, a másik probléma a vizsgálat rövidségével, hogy így nem feltétlen a természetes mozgását végzi a vizsgált személy, mivel tudja, hogy meg van figyelve. (Fehér köpeny effektus.) A mérés hosszának növelésével és a mozgás természetes környezetben való megfigyelésével reményeink szerint egy átfogóbb kép kapható, továbbá kiszűrhetők a például fáradás következtében fellépő elváltozások is.

Tehát az eszközzel a célunk egy hosszabb megfigyelés lehetőségének megalkotása volt, egy 24 órás vérnyomásméréshez (ABPM) vagy egy Holter-monitorhoz hasonlóan. Emellett a cél a könnyű kezelhetőség és felszerelhetőség volt, hogy egymás után sok ember lehessen vele mérni, minél kevesebb állítással. Ez főleg iskolai vagy sportorvosi szűrővizsgálatok során lehet nagyon hasznos, ahol sok ember kell megfigyelni viszonylag rövid idő alatt. Az eszköz lehetőséget nyújt sportolók különböző terhelés folyamán történő, akár rendszeres megfigyelésére, a kapott eredmények összehasonlítására is.

Bár most eszközünk járásvizsgálatban való alkalmazását mutatjuk be, természetesen egyéb mozgások megfigyelésében is szerepet játszhat. Másik fontos alkalmazási területe lehet a sportolók mozgásának megfigyelése, ahol nemcsak a problémák kiszűrése jöhet szóba, hanem egy-egy mozgásforma finomítása, a helyes technika elsajátítása is

# 2. Szakirodalmi áttekintés

A szakirodalmi áttekintés két részre bontható, a járással kapcsolatos problémák és az általunk készített kiértékelés módszereinek bemutatására.

## 2.1. Járásproblémák

Az egészséges járáshoz három szükséges és elégséges feltételnek kell teljesülnie: megfelelő erőbefektetés, megfelelő koordináció és megfelelő érzékelés. Járásszervi elváltozásról akkor beszélhetünk, ha ezek közül legalább az egyik nem teljesül, ugyanis ekkor felborul a járáskép. Járási rendellenesség kialakulásának okai lehetnek genetikai tényezők, betegségek, sérülések vagy elváltozások az alsó végtagban.

Öt típusú elváltozást különítünk el [1]: van az ún. bénult járás (spastic gait), amikor az alany a földön végig húzva a lábát jár. Emellett van az ollózás (scissors gait), ekkor a lábfejek egymás felé vannak fordulva. A lábejtés (steppage gait) során az alany járás közben lábujjhegyét végighúzza a talajon. Vándorgó járás (vaddling gait) esetén az alany oldalirányba nagy kilengéseket tesz felső testből. Az ötödik az előre hajló járás (propulsive gait), ekkor az alany előre dőlve halad. A fent említett elváltozásokat az 1. ábra szemlélteti.


1. ábra Járásproblémák [2]

A KSH 2019-ben történt, a magyar lakosságon végzett egészségfelmérése alapján azt mondhatjuk, hogy a magyar felnőttek negyede nem mozog megfelelően, amely elgyengült izomzathoz, rossz tartáshoz és később járáshibához vezethet, amely további, súlyosabb betegségekhez vezethet. A járásszervi elváltozások szűrésének elmaradottságára utal, hogy szintén eszerint a kiadvány szerint minden ötödik magyar felnőttnek okoz valamekkora nehézséget a járás. Az általuk elszenvedett problémák egy része megfelelő szűrés esetén megelőzhető lehetne.


2. ábra KSH adatai a járásproblémákkal rendelkezőkről [3]

A járáshibák diagnózisát jelenleg az a páciensek egészségügyi anamnéziséből és rövid távon megvizsgált járásából állítják fel, ritkán további laborvizsgálatokra küldik a problémás pácienseket a szakorvosok. Ez a folyamat sok időt vesz igénybe és egyszerre általában egy páciens szűrése végezhető csak. Az általunk fejlesztett eszköz ehhez próbál kiegészítést adni.

Ugyan jelenleg a piacon több hasonló eszköz is jelen van, azonban azok teljesen ki akarják szorítani a MoCap rendszereket. Továbbá a most rendelkezésre álló eszközök zömében nagyon drágák is, ami szintén gátolhatja a tömeges szűrés megvalósítását. Emellett kötöttségük okán alacsony testre szabási lehetőséget nyújtanak.

Az ilyen eszközök a Nansenseansense Suits [4], a Notch [5], vagy a Sens motion [6]. Ezek mind a mienkéhez hasonló mintavételezési idővel rendelkeznek.

## 2.2. Feldolgozó módszerek

A rendszer felépítésének bemutatása a fejlesztések fejezetben részletesen kifejtésre került, az adatok feldolgozásához használt módszerek bemutatása előtt viszont fontosnak tartjuk megmutatni, hogy milyen mért értékekkel dolgoztunk. A méréseket 7 szenzorral rögzítettük, mindegyik szenzor 3 gyorsulásértéket adott vissza (x, y, z tengely irányában). Emellett lehetséges még giroszkóp adatait is vizsgálni, de a mágneses terekről is van információnk. Az adatok a szenzorokból megközelítőleg 120 Hz-en érkeznek, tehát kevés idő alatt viszonylag nagy mennyiségű adatot vagyunk képesek gyűjteni.

### 2.2.1. Adatok vizualizációja

Ahhoz, hogy a mért adatokat jobban megérsük szükséges az adatok vizualizációja. A lábbal páhuzamos gyorsulások értékei jól láthatóak az idő függvényében, de a mozgás síkjára merőlegesen mért értékeknél már nem ilyen egyszerű a helyzet és csak frekvencia tartományban láthatóak jól a jelek.

A járás jó közelítésben periodikus, de a periódus hossza széles tartományban változhat. Az egyes periódusok egymással történő összehasonlításával a ritka, de annál érdekesebb események megkaphatóak, ehhez viszont a jelet lépésekre kell bontani. A felbontásra több lehetőség is van, az egyik a lokális szélsőértékek keresése, a másik pedig az autokorreláció [7].

A periodikus jelek vizsgálatának kézenfekvő módszere a frekvenciatartományba való átlépés. Erre is két fő lehetőség van, az egyik a Fourier-transzformáció, a másik pedig a wavelet-transzformáció. Az egyszerű Fourier-transzformáció esetén a teljes jelet egyben vizsgáljuk, tehát az időbeli változásokat elvesztjük. Ez viszont egy pontos paraméter lehet, például a fáradás elemzésekor. Erre a Short-time Fast Fourer Transformation ad választ, ahol egy mozgó ablakban végzünk FFT-t, így megismerve ezen rövid szakaszok spektrumát.

A másik lehetőség a wavelet transzformáció [8], ahol egy wavelet sereggel söprünk végig az adatokon, így megkapva az egyes frekvenciák amplitúdóját. Az 3. ábrán igen jól látszik, hogy mi a wavalet előnye, az eltérő frekvenciákon eltérő a felbontása, miközben az STFT-nál ez nem így van.

Use of Wavelet and Fast Fourier Transforms in Pharmacodynamics | Journal of Pharmacology and Experimental Therapeutics

3. ábra STFT és wavelet összehasonlítása [8]

A frekvenciatartományban jól látszódnak a mozgás sebességének változásai, de ez a vizsgálataink részben bővebben bemutatjuk.

### 2.2.2. Periódikus jelek vizsgálatára használt módszerek

A periodikus jelek esetén sok esetben lehetséges a jeleket két csoportra bontani, egy általános trendre és egy periodikus részre. Ezt seasonal decompositon-nak [9] szokták nevezni az adatfeldolgozás területén és nagyon sok helyen használják.

A legegyszerűbb megoldás mindössze mozgóátlagokat használ és már ezekkel is használható modellek alkothatóak a mozgóablak méretének jó meghatározásával. Léteznek ennél sokkal kifinomultabb módszerek is, mint például a lokális polinomregressziót használó STL módszer.


4. ábra Szezon dekompozíció [9]

A szétválasztott jelek vizsgálatával lehetséges a hosszabb távú változások vizsgálata, ami főleg hosszabb mérések esetén lehet érdekes számunkra.

### 2.2.3. Adatok anomáliainak detekciója

A mérések hibákkal terheltek, számos esetben előfordulnak olyan kiugró értékek, melyek fizikailag nem lehetségesek vagy az addig követett trendtől nagyon eltérnek. Ezek szűrése történhet egy egyszerű mediánszűréssel vagy ha nem szeretnénk sok információt veszteni, akkor használhatunk kifinomultabb eszközöket is mint például egy DBSCAN alapú detekció. Itt a DBSCAN klaszterező eljárást használjuk arra, hogy a nagyon kiugró adatokat eltávolítsa a méréseinkből [10].

Mivel az adataink periodikusak, ezért létrehozhatunk egy sablon statisztikai módszerekkel, amivel a kiugrásokat szűrhetjük. Ehhez egy konfidenciaintervallumot definiálunk és az ezen kivül eső pontokat elhagyjuk vagy valamilyen módszerrel helyettesítjük. A módszer hibája, hogy előfordulhatnak olyan esetek, amikor más a mozgás, de az nem a mérési hibából adódik, ilyen helyzet például egy lépcsőre való fellépés.

Ha hosszú időn keresztül rögzítjük az adatokat, akkor arra is van lehetőség, hogy az egyes lépéseket klaszterezzük és a nagyon kis elemszámú klasztereket elhagyjuk vagy manuálisan vizsgáljuk. Ezzel a módszerrel a pillanatszerű hibák nem szűrhetők, de egy hosszabban feltálló mérési hiba detektálható, mint amit a szenzor lecsúszása vagy elfordulása okoz.

A korábban bemutatott dekompozíció is alkalmas lehet a hibák megtalálására, mivel ahol nem képes jól előre jelezni a mintát ott jó eséllyel problémás adat lehet. Ennél pontosabb és kifinomultabb módszerek regressziós fákat használnak az anomáliák észlelésére [11].

### 2.2.4. Idősorok osztályozása

Az idősorok osztályozása az élet számos területén fontos, a beszédfelismeréstől a gazdasági adatok elemzéséig csak néhányat kiemelve. Emiatt nagyon sok lehetőség van az adatok feldolgozására az irodalomban.

Az egyik legelső nagy áttörést hozó módszer az LSTM (Long short-term memory) volt, ami a 1990-es évek közepén jelent meg, de csak 2010 környékén kezdett elterjedni. Az ezt követő 6-7 évben az idősorok feldolgozásában az egyik vezető megoldás volt, mára viszont az újabb módszerek a háttérbe szorították [12].

A visszacsatolt hálók családjába tartozik, mivel található benne visszacsatolás, az egyszerű visszacsatolt hálókhoz képest azzal a nagy előnnyel, hogy nem jelenik meg a vanishing gradient problémája, ami a tanításhoz jön elő és a mélyebben lévő rétegek tanulását nehezíti meg.

Az elmúlt években az LSTM cellák a háttérbe kezdtek szorulni, mert használatuk kevésbé gyorsítható, mint az újabb módszereké, ennek ellenére még mindig érnek el vele nagyon nagy eredményeket [13].

Az mindennapi használati eszközökön futó gépi tanuló modellek miatt egyre nagyobb az igény a jól optimalizálható módszerekre, melyek képesek magas pontosságot biztosítani kisebb erőforrások mellett. Ezek miatt indult el a 1D konvolúció használata, ami jól gyorsítható hardveresen és nagyon magas pontosságokra képes.

Az 1D konvolúciós hálók segítségével lehetséges az emberek tevékenységét meghatározni mindössze gyorsulásszenzor adatok alapján. A mi feladatunk is ehhez nagyon hasonló, annyi eltéréssel, hogy nem egyetlen csatorna alapján kell csak a számításainkat végezni, hanem 7 szenzorból jönnek az adatok. A módszerrel elért magas pontosság és az egyszerű futtathatóság lehővé teszi az akár offline alkalmazását a módszernek, tehát nincs szükség az adataikat egy szerverre eljuttatni [14].

A jelek feldolgozásának további lehetősége a jelek STFT-jének vizsgálata. Itt már az egy dimenziósból 2 dimenziós adatot készítünk és ezt már főleg a képfeldolgozás területén elterjed 2D konvolúciós hálókkal tudjuk feldolgozni.

# 3. Eszköz felépítése és működése

MPU-9250részből épül fel. Az első rész 7 MPU9250-es 9 szabadságfokú szenzorból épül fel, melyek közül 2 a combokon, 2 a lábszárakon, 2 a lábfejeken, végül pedig 1 a derékra van rögzítve. A másik rész végzi a szenzoradatok olvasását, mentését és az adatok szerverre való továbbítását.


5. ábra Rendszer felépítése

## 3.1. Szenzorok és azok rögzítése

### 3.1.1. MPU-9250

A mérést végző szenzornak az MPU9250 típusú 9 szabadsági fokú szenzort (3 tengelyű gyorsulásmérő, giroszkóp és magnetométer) választottuk, mivel kis mérete és tömege által kellően kényelmes viselni ahhoz, hogy ne befolyásolja a mérés eredményeit és ne akadályozza viselőjét mindennapi dolgai végzése közben. Emellett költséghatékony és sokoldalú, mely utóbbi a továbbfejlesztések során játszik nagyobb szerepet.

Minden szenzor olvasásához öt kivezetést használunk. Kettőn az áramellátást kapja meg, kettőn kommunikál a vezérléssel és a harmadikon tudjuk megváltoztatni állapotát.

A mérés során sikerült 120 Hz feletti frekvenciával olvasni a szenzorokat, de mivel egy I2C buszra vannak felfűzve és mindössze 2 cím adható a szenzoroknak, ezért szükséges a cím változtatása 2-nél több szenzor esetén. A mérés során a 0x68-as címről olvastunk, ami a címválaszót láb alacsony értéke esetén aktív, a lábra magas jelet kapcsolva a szenzor a 0x69-es címre vált. Ezt használtuk ki és léptettük végig ezt az alacsony jelszintet az egyes szenzorokon, hogy pontosan egy maradjon csak a 0x68-as címen az olvasáshoz. Ezzel a módszerrel sajnos veszünk az elméleti maximális mintavételezési frekvenciából, de így nincs szükség kettesével egy további mikrokontrollerre.

### 3.1.2. CAD tervek és megvalósítása

Ezek közül az érzékelők közül hat a következő módon helyezhető fel a lábra: Kapott egy Fusion 360-ban megtervezett, 3D nyomtatóval kinyomtatott tokozást, amelyen keresztül fut egy gumi gyűrű. Ebbe kell az alanynak belehelyeznie a lábát. A gumigyűrűn elhelyezkedik egy elosztó, amely az előző szenzortól érkező, a következő szenzorhoz vezető és az aktuális szenzor vezetékeit megfelelő módon elosztja.


6. ábra CAD modell és a nyomtatott szenzortartó

A végtagokon elhelyezkedő szenzorok vezetékei egy derékszíjon elhelyezett tokba futnak bele, amelyben kettő Arduino nano, egy Raspberry Pi, a hetedik MPU szenzor és egy akkumulátor helyezkedik el.

## 3.2. Központi egység

### 3.2.1. Arduino

A mérést két Arduino Nano végzi, mivel kis méretű és tömegű és kölcséghatékony. A következő módon osztják meg az érzékelőket: egyik mér egy lábon levő három szenzorral, a másik a másik lábon levő három szenzorral és a derék közepén levő szenzorral. Emiatt lehetne eltérés a két mikrokontroller mintavételezési ideje között, de ezt szoftveresen ki tudtuk küszöbölni.

Az Arduinok I²C buszon keresztül kommunikálnak az érzékelőkkel. Mivel egyszerre csak egy szenzor olvasását tudjuk elvégezni, így egy izgalmas megoldáshoz folyamodtunk. Egy szenzor két állapotban lehet: egy alvó állapotban, melykor 0x68 címen érhető el, és egy aktív állapotban, amikor 0x69 címen érhetjük el. Bármely érzékelőt tetszőlegesen tudjuk váltogatni e két állapot között.

A vezeték nélküli kommunikációért egy Raspberry Pi 4 B típusú mikroszámítógépet használtunk, mely se nem kicsi és könnyű, se nem költséghatékony, azonban ez rendelkezett olyan megfelelő specifikációkkal, mely alkalmas megfelelő gyorsasággal és mennyiségben továbbítani az adatot. Az Arduinokkal soros porton keresztül kommunikál. A befolyt adatot a Pi 4 GB melyről befolyt adatokat CSV (Comma-separated values) fájlba kiment és továbbít az előre kijelölt számítógépre.

Jogosan merül fel a kérdés, miért nem egyetlen mikrokontrolleren vagy mikroszámítógépen végezzük mind a mintavételezést, mind pedig a továbbítást. Ennek oka, hogy nem lehetséges a szenzorok megfelelő címzése, a címzésből adódó nehézségek pedig egy olvasó eszközt használva nagyon lassúvá tennék a mérést.

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

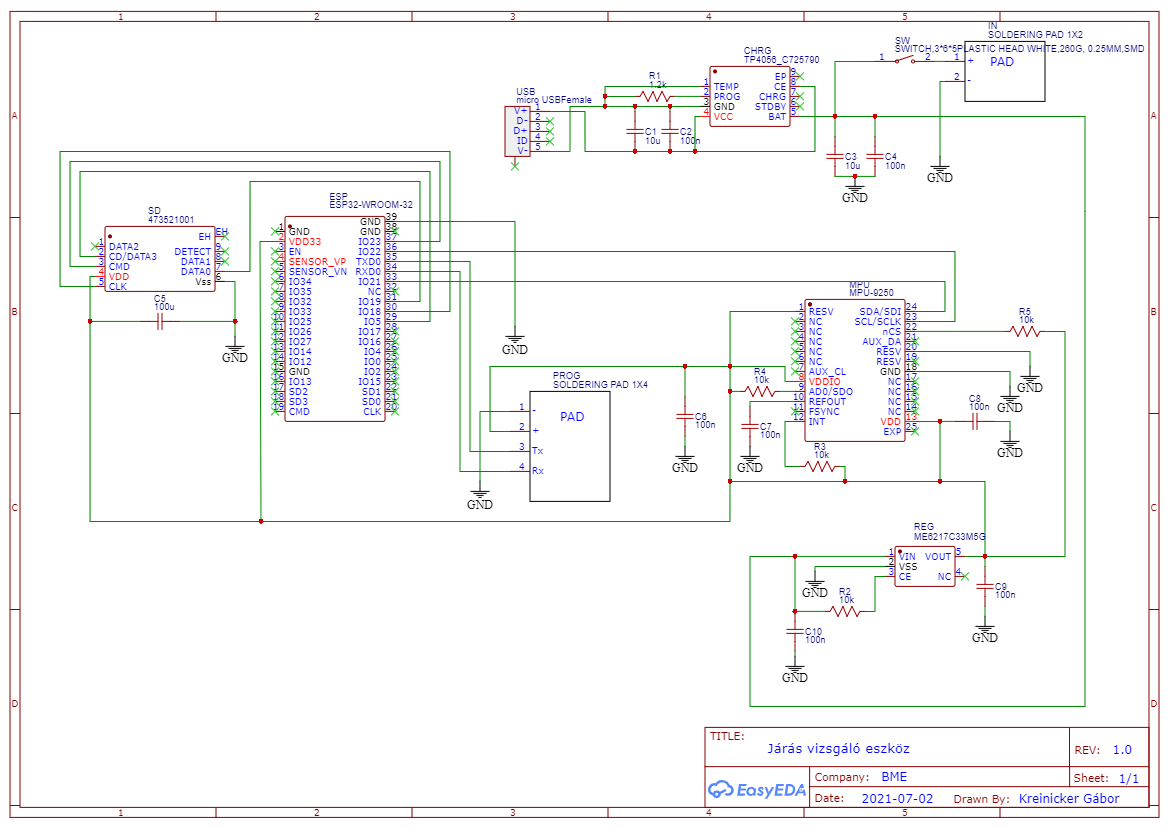
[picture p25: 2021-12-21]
TDK 2021/Képek/Schematic_Jaras_2021-11-13.png

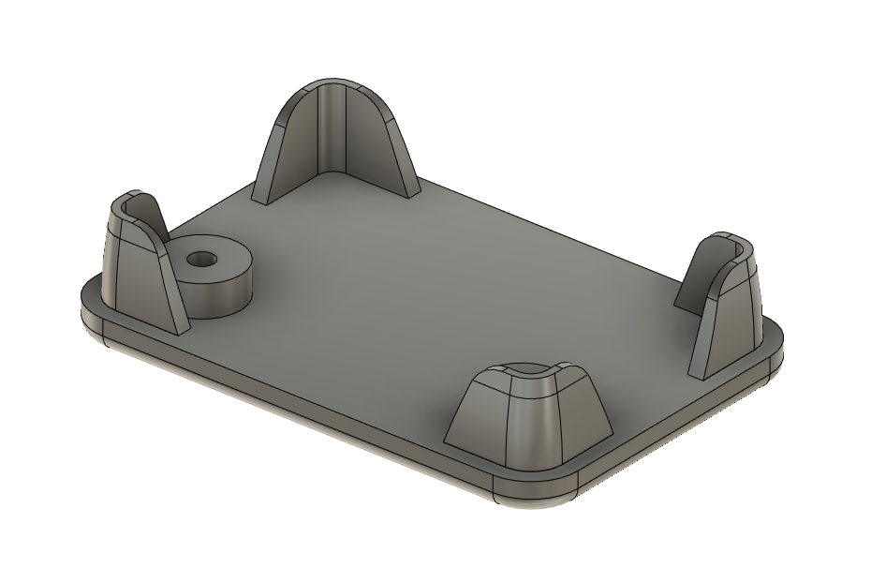
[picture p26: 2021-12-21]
TDK 2020/Dokumentumok/Design_2.png

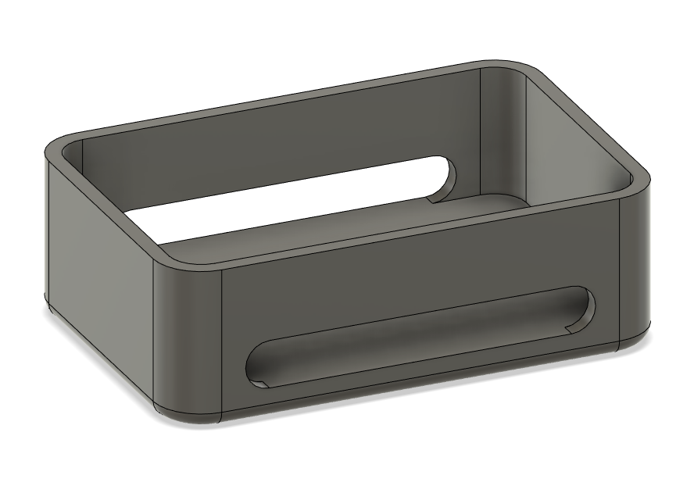
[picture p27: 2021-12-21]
TDK 2020/Dokumentumok/Design_1.png

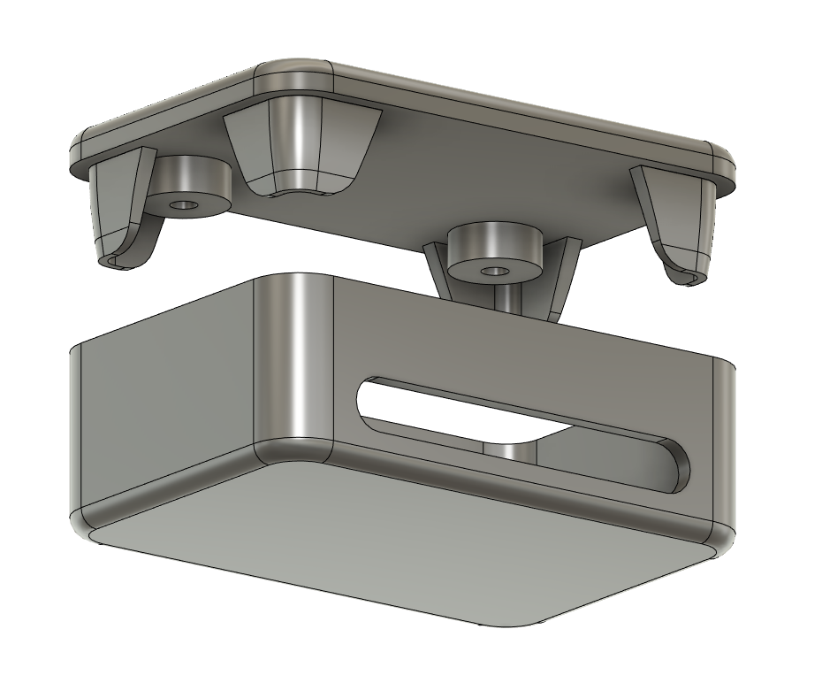
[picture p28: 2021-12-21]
TDK 2020/Dokumentumok/Design_4.png

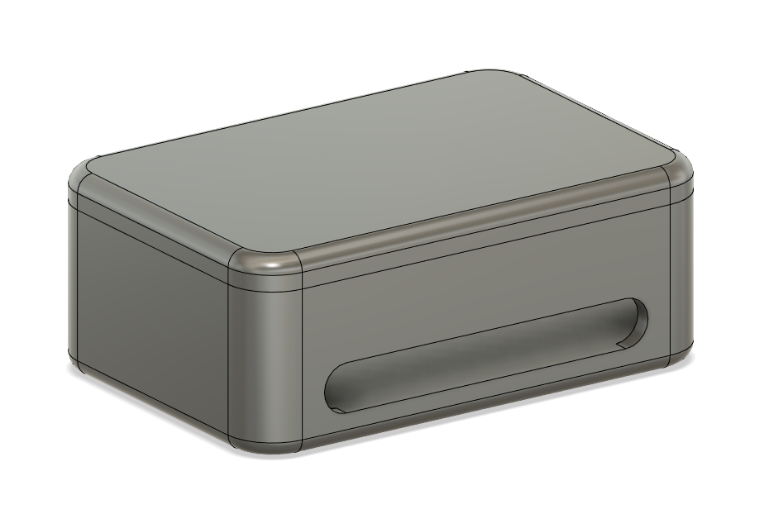
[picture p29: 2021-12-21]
TDK 2020/Dokumentumok/Design_3.png

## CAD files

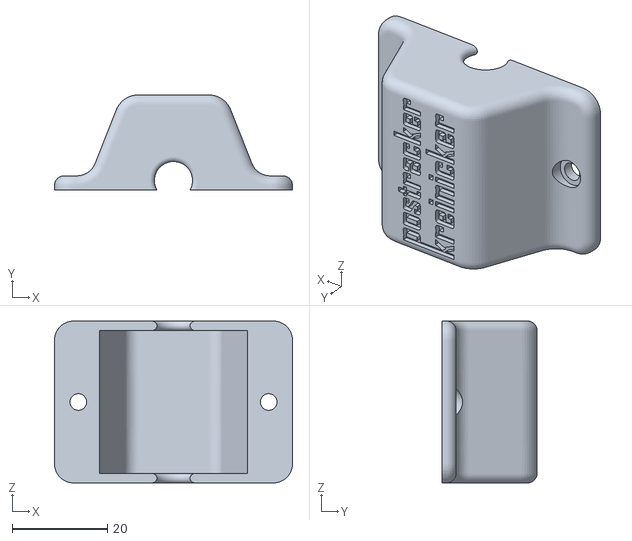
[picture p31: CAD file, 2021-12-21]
PosTracker/Alkatrészek/Felső_v3.0.stl
50.0 x 20.0 x 34.0

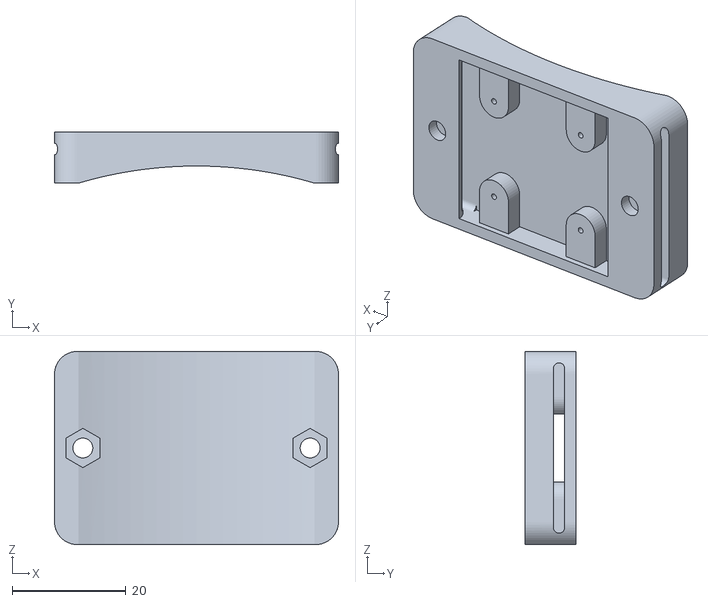
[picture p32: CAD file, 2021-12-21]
PosTracker/Alkatrészek/Alsó_v3.0.stl
50.0 x 9.00 x 34.0

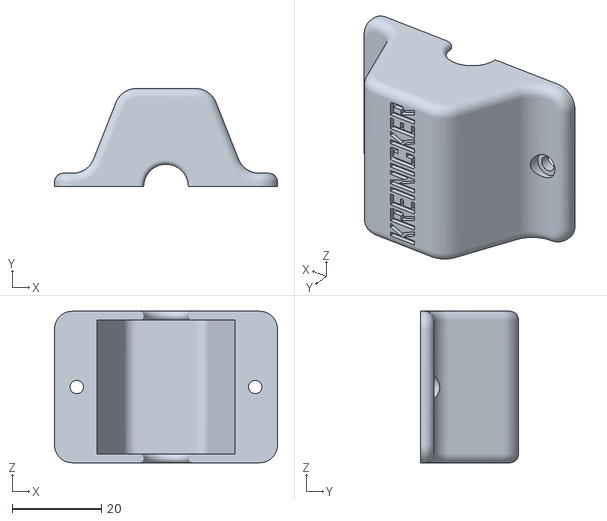
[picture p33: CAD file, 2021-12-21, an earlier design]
PosTracker/Alkatrészek/Felső_v1.0.stl
50.0 x 22.0 x 34.0

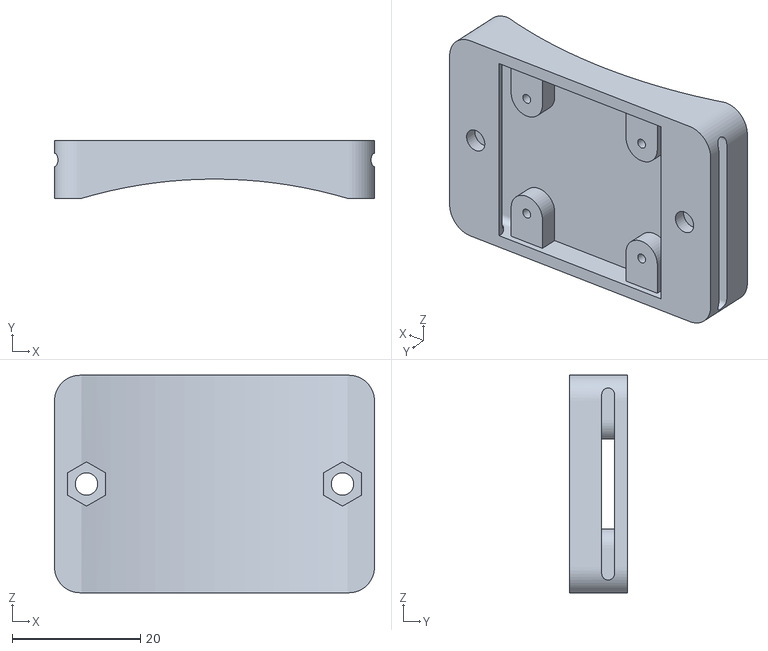
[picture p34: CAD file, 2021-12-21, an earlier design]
PosTracker/Alkatrészek/Alsó_v2.0.stl
50.0 x 9.00 x 34.0

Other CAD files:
PosTracker/Alkatrészek/Felső_v2.0.stl
PosTracker/Alkatrészek/Alsó_v1.0.stl

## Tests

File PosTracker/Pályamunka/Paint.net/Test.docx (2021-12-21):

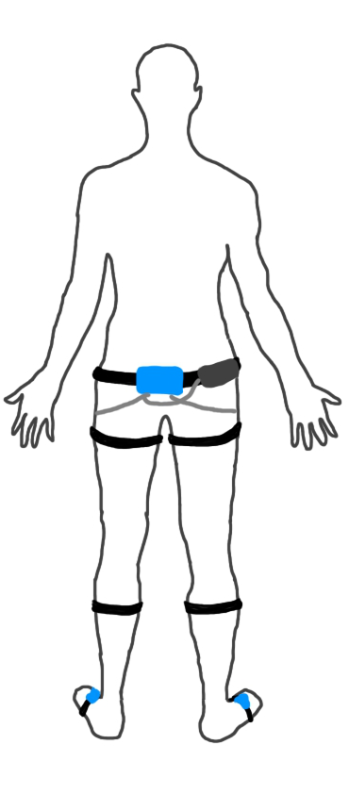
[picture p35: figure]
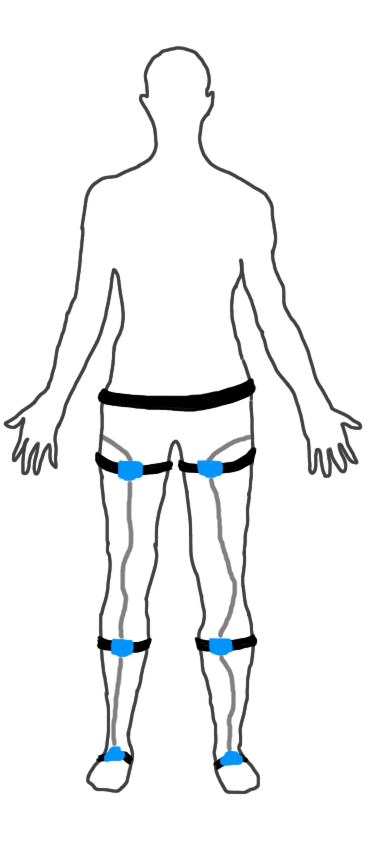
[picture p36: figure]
A képen rajz látható Automatikusan generált leírás

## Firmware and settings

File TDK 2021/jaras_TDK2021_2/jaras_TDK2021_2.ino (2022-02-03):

/*
Advanced_I2C.ino
Brian R Taylor
brian.taylor@bolderflight.com

Copyright (c) 2017 Bolder Flight Systems

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
THE SOFTWARE IS PROVIDED "AS IS", WITHOUT WARRANTY OF ANY KIND, EXPRESS OR IMPLIED, INCLUDING 
BUT NOT LIMITED TO THE WARRANTIES OF MERCHANTABILITY, FITNESS FOR A PARTICULAR PURPOSE AND 
NONINFRINGEMENT. IN NO EVENT SHALL THE AUTHORS OR COPYRIGHT HOLDERS BE LIABLE FOR ANY CLAIM, 
DAMAGES OR OTHER LIABILITY, WHETHER IN AN ACTION OF CONTRACT, TORT OR OTHERWISE, ARISING FROM, 
OUT OF OR IN CONNECTION WITH THE SOFTWARE OR THE USE OR OTHER DEALINGS IN THE SOFTWARE.
*/

#include "MPU9250.h"

// an MPU9250 object with the MPU-9250 sensor on I2C bus 0 with address 0x68
MPU9250 IMU1(Wire,0x68);
MPU9250 IMU2(Wire,0x69);
int status1;
int status2;
int t = 1;
void setup() {
  // serial to display data
  Serial.begin(115200);
  pinMode(13, OUTPUT);
  delay(100);
  digitalWrite(13, HIGH);
  delay(100);

  // start communication with IMU 
  status1 = IMU1.begin();
  if (status1 < 0) {
    Serial.println("IMU initialization unsuccessful");
    Serial.println("Check IMU wiring or try cycling power");
    Serial.print("Status: ");
    Serial.println(status1);
    while(1) {}
  }
  status2 = IMU2.begin();
  if (status2 < 0) {
    Serial.println("IMU initialization unsuccessful");
    Serial.println("Check IMU wiring or try cycling power");
    Serial.print("Status: ");
    Serial.println(status2);
    while(1) {}
  }
  IMU1.setSrd(0);
  IMU2.setSrd(0);
  IMU1.setAccelRange(MPU9250::ACCEL_RANGE_8G);
  IMU1.setGyroRange(MPU9250::GYRO_RANGE_500DPS);
  IMU1.setDlpfBandwidth(MPU9250::DLPF_BANDWIDTH_20HZ);
  IMU2.setAccelRange(MPU9250::ACCEL_RANGE_8G);
  IMU2.setGyroRange(MPU9250::GYRO_RANGE_500DPS);
  IMU2.setDlpfBandwidth(MPU9250::DLPF_BANDWIDTH_20HZ);
  Serial.print("Time,Sensor,Acc_x,Acc_y,Acc_z,Gyro_x,Gyro_z,Gyro_z\n");
}



void loop() {
  // read the sensor
  
  Serial.print(millis());
  Serial.print(",0,");
  IMU1.readSensor();
  Serial.print(IMU1.getAccelX_mss(),6);
  Serial.print(",");
  Serial.print(IMU1.getAccelY_mss(),6);
  Serial.print(",");
  Serial.print(IMU1.getAccelZ_mss(),6);
  Serial.print(",");
  Serial.print(IMU1.getGyroX_rads(),6);
  Serial.print(",");
  Serial.print(IMU1.getGyroY_rads(),6);
  Serial.print(",");
  Serial.print(IMU1.getGyroZ_rads(),6);
  Serial.print("\n");

  //delay(t);
  Serial.print(millis());
  Serial.print(",1,");
  IMU2.readSensor();
  Serial.print(IMU2.getAccelX_mss(),6);
  Serial.print(",");
  Serial.print(IMU2.getAccelY_mss(),6);
  Serial.print(",");
  Serial.print(IMU2.getAccelZ_mss(),6);
  Serial.print(",");
  Serial.print(IMU2.getGyroX_rads(),6);
  Serial.print(",");
  Serial.print(IMU2.getGyroY_rads(),6);
  Serial.print(",");
  Serial.print(IMU2.getGyroZ_rads(),6);
  Serial.print("\n");
}

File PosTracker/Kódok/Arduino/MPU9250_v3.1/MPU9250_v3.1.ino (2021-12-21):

    #include <I2Cdev.h>
    #include <MPU6050.h>

    #if I2CDEV_IMPLEMENTATION == I2CDEV_ARDUINO_WIRE
    #include "Wire.h"
    #endif

    MPU6050 mpu_0(0x68);
    MPU6050 mpu_1(0x68);
    MPU6050 mpu_2(0x68);

    int16_t ax_0, ay_0, az_0, ax_1, ay_1, az_1, ax_2, ay_2, az_2;
    int16_t gx_0, gy_0, gz_0, gx_1, gy_1, gz_1, gx_2, gy_2, gz_2;

    #define OUTPUT_READABLE_ACCELGYRO


    #define LED_PIN 13
    bool blinkState = false;

    int s0 = 9;
    int s1 = 10;
    int s2 = 11;

    int SIG_pin = 0;

    const int MPU=0x68;

    unsigned long time;





void setup() {



  pinMode(s0, OUTPUT); 
  pinMode(s1, OUTPUT); 
  pinMode(s2, OUTPUT); 

  #if I2CDEV_IMPLEMENTATION == I2CDEV_ARDUINO_WIRE
      Wire.begin();
  #elif I2CDEV_IMPLEMENTATION == I2CDEV_BUILTIN_FASTWIRE
      Fastwire::setup(400, true);
  #endif
  
  Serial.begin(115200);

  
  // ================= MPU: 0 =================
  
  digitalWrite(s0, LOW);
  digitalWrite(s1, HIGH);
  digitalWrite(s2, HIGH);
  delay(5);
  Wire.begin();
  Wire.beginTransmission(MPU);
  Wire.write(0x6B);
  Wire.write(0);
  Wire.endTransmission(true);
  delay(15);
  mpu_0.initialize();
  //Serial.println("Eszkoz teszt (0) ...");
  //Serial.println(mpu_0.testConnection() ? "  MPU9250 (0) csatlakozas sikeres" :  "  MPU9250 (0) csatlakozas sikertelen");
  delay(5);

  
  // ================= MPU: 1 =================
  
  digitalWrite(s0, HIGH);
  digitalWrite(s1, LOW);
  digitalWrite(s2, HIGH);
  delay(5);
  Wire.begin();
  Wire.beginTransmission(MPU);
  Wire.write(0x6B);
  Wire.write(0);
  Wire.endTransmission(true);
  delay(15);
  mpu_1.initialize();
  //Serial.println("Eszkoz teszt (1) ...");
  //Serial.println(mpu_1.testConnection() ? "  MPU9250 (1) csatlakozas sikeres" :  "  MPU9250 (1) csatlakozas sikertelen");
  delay(5);

  
  // ================= MPU: 2 =================
  
  digitalWrite(s0, HIGH);
  digitalWrite(s1, HIGH);
  digitalWrite(s2, LOW);
  delay(5);
  Wire.begin();
  Wire.beginTransmission(MPU);
  Wire.write(0x6B);
  Wire.write(0);
  Wire.endTransmission(true);
  delay(15);
  mpu_2.initialize();
  //Serial.println("Eszkoz teszt (2) ...");
  //Serial.println(mpu_2.testConnection() ? "  MPU9250 (3) csatlakozas sikeres" :  "  MPU9250 (2) csatlakozas sikertelen");
  delay(5);
  
  
  
  pinMode(LED_PIN, OUTPUT);
  }






void loop() {


  time = micros();


  // ================= MPU: 0 =================
  
  digitalWrite(s0, LOW);
  digitalWrite(s1, HIGH);
  digitalWrite(s2, HIGH);
  delay(1);
  mpu_0.getMotion6(&ax_0, &ay_0, &az_0, &gx_0, &gy_0, &gz_0);
  #ifdef OUTPUT_READABLE_ACCELGYRO
      Serial.print(time); Serial.print("\t");
      Serial.print("0\t");
      Serial.print(ax_0); Serial.print("\t");
      Serial.print(ay_0); Serial.print("\t");
      Serial.print(az_0); Serial.print("\t\n");
      //Serial.print(gx_0); Serial.print("\t");
      //Serial.print(gy_0); Serial.print("\t");
      //Serial.println(gz_0);
    #endif
    delay(1);

  
  // ================= MPU: 1 =================
  
  digitalWrite(s0, HIGH);
  digitalWrite(s1, LOW);
  digitalWrite(s2, HIGH);
  delay(1);
  mpu_1.getMotion6(&ax_1, &ay_1, &az_1, &gx_1, &gy_1, &gz_1);
  #ifdef OUTPUT_READABLE_ACCELGYRO
      Serial.print(time); Serial.print("\t");
      Serial.print("1\t");
      Serial.print(ax_1); Serial.print("\t");
      Serial.print(ay_1); Serial.print("\t");
      Serial.print(az_1); Serial.print("\t\n");
      //Serial.print(gx_1); Serial.print("\t");
      //Serial.print(gy_1); Serial.print("\t");
      //Serial.println(gz_1);
  #endif
  delay(1);

  
  // ================= MPU: 2 =================
  
  digitalWrite(s0, HIGH);
  digitalWrite(s1, HIGH);
  digitalWrite(s2, LOW);
  delay(1);
  mpu_2.getMotion6(&ax_2, &ay_2, &az_2, &gx_2, &gy_2, &gz_2);
  #ifdef OUTPUT_READABLE_ACCELGYRO
      Serial.print(time); Serial.print("\t");
      Serial.print("2\t");
      Serial.print(ax_2); Serial.print("\t");
      Serial.print(ay_2); Serial.print("\t");
      Serial.print(az_2); Serial.print("\t\n");
      //Serial.print(gx_2); Serial.print("\t");
      //Serial.print(gy_2); Serial.print("\t");
      //Serial.println(gz_2);
   #endif
   delay(1);


    blinkState = !blinkState;
    digitalWrite(LED_PIN, blinkState);
   }
